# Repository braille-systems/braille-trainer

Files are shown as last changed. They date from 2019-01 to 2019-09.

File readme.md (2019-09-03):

 # Braille Trainer (old repository)
 **New Braille Trainer repositories:** <br>
**[braille3](https://github.com/zuevval/braille3/)** <br>
**[braille3parts](https://github.com/zuevval/braille3parts/)** <hr>

Braille Trainer: a  device and a set of programs in Python made for visually impared. The main purpose is learning Braille alphabet.<br>
**ENG:**<br>
**General information:** [wiki](https://github.com/zuevval/braille/wiki) <br>
**Articles (drafts), information about previous studies:** [папка doc](https://github.com/zuevval/braille/tree/master/doc) <br>
**Progress of the project during FabLab Polytech winter school-2019:** [Projects/1/](https://github.com/zuevval/braille/projects/1) <br>
**Miscellaneous data from a former leader of BrailleTrainer project Gleb Miroshnik:** [Dropbox](https://www.dropbox.com/sh/m1fgdtpio7jf0r5/AADZN6ftSRqo8V_MonHDIt2Xa?dl=0) <br>
**Contacts:** valera.zuev.zva@gmail.com - Валерий Зуев <br>
**YouTube:** [https://www.youtube.com/channel/UC_SwOSaCvuRJdq-IEFu5GWw](https://www.youtube.com/channel/UC_SwOSaCvuRJdq-IEFu5GWw)
<br>
**An application for a contest "Reactor 2019:"** [reactor.su/project/12096](https://reactor.su/project/12096)<br>
<br>
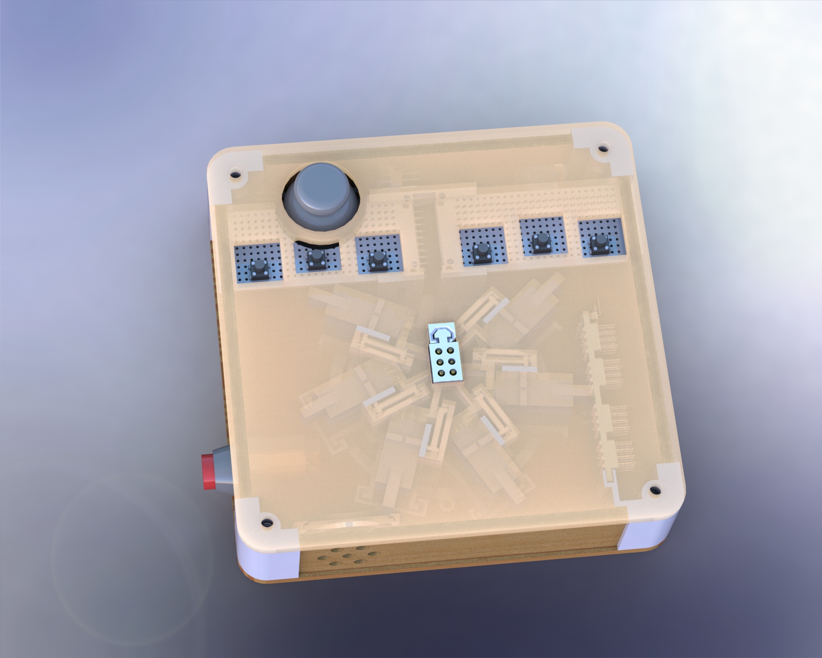
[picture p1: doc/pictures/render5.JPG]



<br>
<br>
**RUS:**<br>
**Основная информация:** [вики](https://github.com/zuevval/braille/wiki) <br>
**Заготовки статей и материалы предшествующих исследований:** [папка doc](https://github.com/zuevval/braille/tree/master/doc) <br>
**Ход проекта в рамках Школы ФабЛаб (зима 2019):** [Projects/1/](https://github.com/zuevval/braille/projects/1) <br>
**Материалы, доставшиеся от Глеба Мирошника:** [Dropbox](https://www.dropbox.com/sh/m1fgdtpio7jf0r5/AADZN6ftSRqo8V_MonHDIt2Xa?dl=0) <br>
**Контакты:** valera.zuev.zva@gmail.com - Валерий Зуев <br>
**YouTube:** [https://www.youtube.com/channel/UC_SwOSaCvuRJdq-IEFu5GWw](https://www.youtube.com/channel/UC_SwOSaCvuRJdq-IEFu5GWw)
<br>
**Заявка на конкурс "Реактор 2019:"** [reactor.su/project/12096](https://reactor.su/project/12096)

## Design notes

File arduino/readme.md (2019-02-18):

**Arduino-код (одна папка - один скетч)** <br>
* calibrate - калибровочный скрипт шеститочечной 
ячейки на серво
* printText общается по Serial с функциями из serial_hex.py и 
joystick.py из папки python. Печатает заданный текст; выводит нажатия джойстика и кнопки 
режима звука. Работает при прямом подключении серво.
* printTextPWM - то же, что printText, но работает при подключении серво 
через 16-канальный импульсный PWM-драйвер

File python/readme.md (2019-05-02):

Для работы синтеза речи в Windows:
1. [download RHVoice (Google Drive)](https://nvda.ru/links/rhvoice-0.7.1-sapi5.php)
Если не устраивает конкретно этот дистрибутив: [RHVoice - все версии, в т. ч. портативная](https://nvda.ru/sintezator-rhvoice#komplekt-rhvoice-v071-sapi5-razdelnye-komponenty)
1. Запустить инсталлер RHVoice (`General/RHVoice-v0.7.1-setup.exe`)
1. После успешной установки запустить инсталлер голоса, сейчас это Ирина (`Voice/RHVoice-voice-Russian-Irina-v4.0-setup.exe`)
1. `pip3 install pyttsx3` - набрать в терминале

После этих действий должны проигрываться названия приложений в меню и прочее (заметки, ...)

Для работы распознования аудио понадобится:
1. ``pip install pyaudio``
1. ``pip install speechrecognition``
1. ``pip install pocketsphinx``

Для установки pocketsphinx может потребоваться установленный swig:
инструкция: http://www.swig.org/download.html
(если установка pocketsphinx проходит нормально через pip, Swig не нужен)

Для работы с Serial используется библиотека pySerial<br>
https://github.com/pyserial/pyserial
https://pythonhosted.org/pyserial/
Для установки `pip install pyserial`

Для работы listen необходимо добавить в папку python'a:
~\Lib\site-packages\pocketsphinx\model
файлы: (содержимое папки "for_ps")
calc.jsgf
my_dicy_out.dic
всю папку zero_ru.cd_cont_4000

Эталонные версии пакетов, с которыми проверена работа:
1. Python 3.7.2
1. PyAudion 0.2.11
1. PyQt5 5.12
1. PyQt5-sip 4.19.14
1. pyserial 3.4
1. SpeechRecognition 3.8.1
1. pocketsphinx 0.1.15

**alphabet.py** - приложение - азбука<br>
**audio.py** отвечает за проигрывание буквы в .wav из папки 
"audio" и вывод остальных фраз; только для Windows<br>
**clock.py** - приложение - часы<br>
**edu.py, edu_app.py** - обучающее приложение<br>
**joystick.py** - обработка нажатий джойстика, 
пришедших по Serial<br>
**letter.py** - вывод буквы на экран в PyQT5<br>
**listen.py** - распознавание произнесённой буквы 
(вариант с сервисом google, если не получается, вызывает pocketsphinx распознование)<br>
**main.py** - **запуск всего (меню 
приложений)**<br>
**notes.py** - приложение - заметки (в 
разработке)<br>
**serial_get_name.py** - автоопределение 
COM-порта, к которому подключён тренажёр<br>
**serial_hex.py** выводит строку (алфавит) в Serial. Соответствует скетчу print_letters в 
папке arduino. Также проигрывает буквы вслух (только на Windows) <br>
**ui_letter.py** - наполнение (дизайн) для 
вывода буквы на экран средствами PyQT5. Логика 
в letter.py<br>

**alphabet.py** - приложение - азбука<br> **audio.py** отвечает за 
проигрывание буквы в .wav из папки "audio" и вывод остальных фраз; 
только для Windows<br> **clock.py** - приложение - часы<br>** **edu.py, 
edu_app.py** - обучающее приложение<br> **joystick.py** - обработка 
нажатий джойстика, пришедших по Serial<br> **letter.py** - вывод буквы 
на экран в PyQT5<br> **listen.py** - распознавание произнесённой буквы 
(вариант с сервисом google)<br> **main.py** - **запуск всего (меню 
приложений)**<br> **notes.py** - приложение - заметки (в разработке)<br> 
**serial_get_name.py** - автоопределение COM-порта, к которому подключён 
тренажёр<br> **serial_hex.py** выводит строку (алфавит) в Serial. 
Соответствует скетчу print_letters в папке arduino. Также проигрывает 
буквы вслух (только на Windows) <br> **ui_letter.py** - наполнение 
(дизайн) для вывода буквы на экран средствами PyQT5. Логика в 
letter.py<br>

Ссылка на описание аудифайлов
https://docs.google.com/spreadsheets/d/1J9BtCmSqfUPkXovssfOHMlftX5HE0grbqLEqsHJY1Zc/edit#gid=0

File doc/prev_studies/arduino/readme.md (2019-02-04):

# Code developed during a period from 2016 to 2018
* drum_2016 - код для кругового дисплея Валеры, написанный Мишей Ракицким
* Остальное - различные версии, написанные Глебом, Савой и другими.

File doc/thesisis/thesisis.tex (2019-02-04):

%XeLaTeX+makeIndex+BibTeX OR LuaLaTeX+...
\documentclass[a4paper,12pt]{article} %14pt - extarticle
\usepackage[utf8]{inputenc} %русский язык, не менять
\usepackage[T2A, T1]{fontenc} %русский язык, не менять
\usepackage[english, russian]{babel} %русский язык, не менять
\usepackage{fontspec} %различные шрифты
\setmainfont{Times New Roman}

%\defaultfontfeatures{Ligatures={TeX},Renderer=Basic}
\usepackage[hyphens]{url} %ссылки \url с переносами
\usepackage{hyperref} %гиперссылки href
\hypersetup{pdfstartview=FitH,  linkcolor=blue, urlcolor=blue, colorlinks=true} %гиперссылки
\usepackage{subfiles}%включение тех-текста
\usepackage{graphicx} %изображения
\usepackage{float}%картинки где угодно
\usepackage{textcomp}

%\usepackage[dvips]{color} %попытка добавить цвета типа OliveGreen. Пропадают все картинки

\usepackage{dsfont}%мат. символы
%\usepackage[style=gost-footnote]{biblatex} %ГОСТ https://www.ctan.org/pkg/biblatex-gost С ним только хуже! Не использовать его!
\newcommand{\ovr}[1]{\overrightarrow{#1}}
\usepackage{listings} %code formatting
\lstset{language=sql,keywordstyle=\color{blue},tabsize=2,breaklines=true,
morekeywords={if, CONCAT, is}}
%хорошая статья об этом пакете: http://mydebianblog.blogspot.com/2012/12/latex.html

\addto\captionsrussian{\def\refname{Использованные источники}}

\begin{document}
\title{Описание проекта <<Тренажёр Брайля>>}
\author{Валерий Зуев}
\maketitle
\section{Краткое описание}
Предлагается собрать и запрограммировать \textbf{тренажёр Брайля} -- прибор для обучения слепых людей \textbf{шрифту Брайля}. Идея шрифта Брайля -- представление буквы в виде группы выпуклых точек, оттиснутых на бумаге или иной поверхности (иногда такие есть на упаковках с лекарствами). Слепые могут читать на ощупь, но должны выучить обозначение каждой буквы.\\
Основной элемент прибора -- электромеханическая \textbf{ячейка Брайля}, которая посредством сервоприводов воспроизводит буквы шеститочечного шрифта Брайля. Планируется, ориентируясь на разработанный заблаговременно прототип ячейки, создать несколько обучающих программ для ПК или одноплатного компьютера Nano Pi. Непосредственно управлять сервоприводами будет контроллер Arduino Uno; планируется написать программу для него. Помимо того, планируется усовершенствовать и доработать ячейку Брайля.

\section{Актуальность}
Число инвалидов по зрению в России по состоянию на 2011 год оценивалось в 103 тысячи человек, и предполагается дальнейшее увеличение их количества\cite{stat}. При этом число людей, владеющих шрифтом Брайля, снижается \cite{brailleLower}. Причина как в относительной дороговизне специальных книг, так и в сложности обучения, в неразвитости системы обучения. При этом знание шрифта Брайля позволяет слепому читать, учиться и даже работать.\\
В настоящее время выпускаются дисплеи Брайля -- приставки к компьютеру с компактными пьезоэлектрическими ячейками. Эти устройства позволяют читать до 80 символов Брайля одновременно и вводить текст с помощью особой клавиатуры из восьми клавиш (по одной на каждую точку в букве азбуки Брайля). Основной их недостаток -- цена (в среднем 150 тысяч русских рублей по состоянию на январь 2019 года).

\section{Предшествующие работы}
Были предприняты многочисленные попытки создания более доступного дисплея Брайля.  В их числе нитиноловые \cite{sma}, на основе электрической стимуляции кожи \cite{kaji1} \cite{kaji2}, на основе электромоторов \cite{bristol}, круговые \cite{rotDisp}. В 2016 году автор статьи пытался разработать собственную конструкцию кругового дисплея Брайля (рис. \ref{myRoundDisp}), но из-за сложности создания миниатюрной механики проект был свёрнут.\\

\begin{figure}[h!]
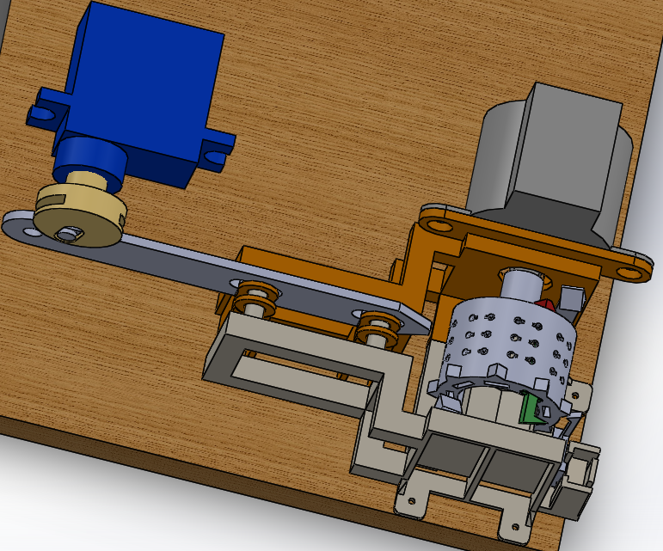
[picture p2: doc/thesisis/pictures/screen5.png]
\center{}
\caption{Компьютерная модель нереализованного кругового дисплея Брайля}
\label{myRoundDisp}
\end{figure}

В 2016-2017 годах команда под руководством магистра кафедры <<Теоретическая Механика>> Глеба Андреевича Мирошника создала несколько прототипов тренажёра Брайля - дисплея с одной ячейкой, ориентированного на обучение слепых, а не на длительное чтение \cite{gleb}. После ряда попыток создать ячейку Брайля на основе сервоприводов было решено отказаться от них в пользу обычной, более надёжной пьезоэлектрической ячейки. Такой тренажёр компактный, но трудновоспроизводимый: ячейки дисплея Брайля, по имеющимся данным, не продаются отдельно от дисплеев.

\section{Цели работы}
Цель - создать надёжный и простой в изготовлении тренажёр Брайля и комплекс программ для него. Предлагается развить идею, реализованной командой Г. А. Мирошника. Ячейка Брайля будет создана с применением только доступных компонентов (сервоприводов, контроллеров Arduino и/или Raspberry Pi, деталей, пригодных к изготовлению на большинстве 3D-принтеров). За счёт открытого распространения материалов проекта предполагается возможным легко воспроизводить дисплей и сделать обучение шрифту Брайля доступным для людей по всему миру.

\section{Описание конструкции}
Создан прототип ячейки (рис. \ref{photo1}). Точки символа Брайля - головки подвижных штырьков. Штырьки приклеены к рычагам и двигаются вверх-вниз, отчего точки появляются над поверхностью или убираются внутрь. Движение обеспечивают сервоприводы с насаженными на вал шестернями. Каждый рычаг на противоположном от штырька конце имеет зубчатую рейку, которой передаётся движение шестерни.

\begin{figure}[h!]
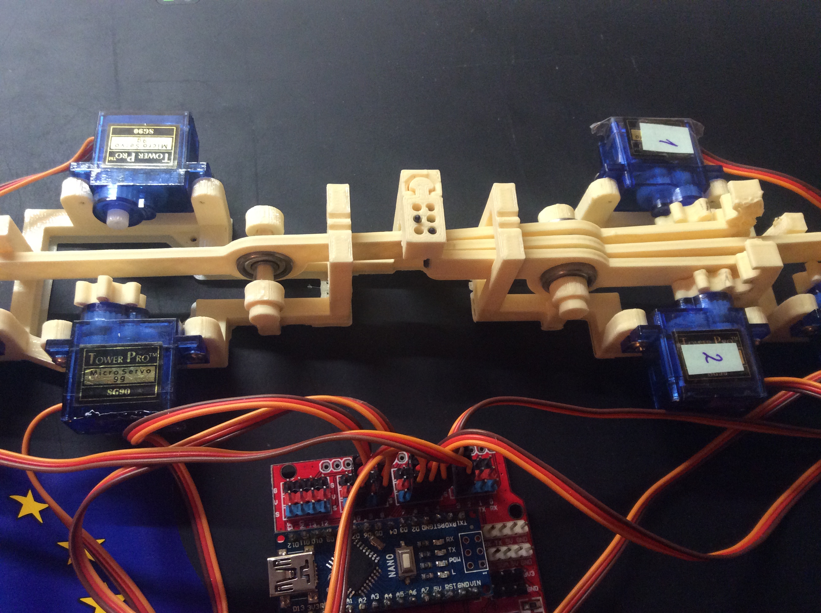
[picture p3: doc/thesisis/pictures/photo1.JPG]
\center{}
\caption{Прототип ячейки Брайля}
\label{photo1}
\end{figure}

\section{Текущие задачи и планируемое решение задач}
\subsection{Базовые задачи}
\begin{itemize}
\item{}Написать программу для Arduino, которая выводит текст, отправленный через Serial.
\item{}Снабдить дисплей органами управления (кнопки или джойстик). По нажатию кнопки передавать сигнал по Serial.
\item{}Составить два обучающих приложения на Python, общающихся с Arduino через Serial. Одно для запоминания азбуки: воспроизводит на экране буквы и сопровождает звуком; второе - тест на знание азбуки: дисплей выводит букву, пользователь должен произнести её вслух. Компьютер определяет с помощью распознавания голоса, верно ли ответил пользователь.
\item{}Спроектировать и создать корпус устройства
\item{}Разместить материалы проекта в свободном доступе (к примеру, на платформе Github), чтобы предоставить возможность создания подобного прибора всем желающим.
\end{itemize}
\subsection{Приблизительный список дополнительных задач}
\begin{itemize}
\item{}Адаптировать программы на Python к контроллеру Raspberry Pi/Nano Pi. Создать отдельный опциональный модуль хост-контроллера с динамиком и микрофоном в собственном корпусе.
\item{}Составить меню тренажёра Брайля (список приложений) с возможностью навигации джойстиком. Названия пунктов меню выводятся с помощью ячейки Брайля или произносятся вслух динамиками компьютера.
\item{}Написать иные программы (обучающие или, возможно, для чтения текста). Пример - часы (показать время с помощью ячейки Брайля).
\item{}Повысить компактность ячейки Брайля: взять подшипники меньшего размера, перекомпоновать сервоприводы (разместить два из них на другой стороне рычагов).
\item{}Попробовать управлять серво с помощью ШИМ контроллера PCA9685
\item{}Создать ячейку с восемью точками (расширенный шрифт Брайля).
\item{}Снабдить тренажёр особой клавиатурой из восьми клавиш. Снабдить встроенным динамиком и, возможно, лампочками для зрячего иструктора (индикатор питания и подключения хост-контроллера).
\item{}Предусмотреть в конструкции механизм для автокалибровки ячейки.
\item{}Уделить внимание не техническим аспектам (презентовать проект, возможно, создать видеоклип/сайт проекта).
\end{itemize}

\begin{thebibliography}{99}
\bibitem{gleb}{Тренажёр Брайля. Глеб Андреевич Мирошник. [Электронный ресурс] \url{http://www.brailletrainer.ru}}
\bibitem{sma}{Microtuators of SMA for Braille display system \url{https://www.researchgate.net/publication/232633029_Microtuators_of_SMA_for_Braille_display_system}}
\bibitem{kaji1}{Electro-Tactile Display with Force Feedback. Hiroyuki Kajimoto, Naoki Kawakami, Taro Maeda and Susumu Tachi: Graduate School of Information Science and Technology, The University of Tokyo. [Электронный ресурс]. \url{http://citeseerx.ist.psu.edu/viewdoc/download?doi=10.1.1.493.2786&rep=rep1&type=pdf}}
\bibitem{kaji2}{Electro-Tactile Display with Tactile Primary Color Approach.
Hiroyuki Kajimoto, Naoki Kawakami, Susumu Tachi. Graduate School of
Information Science and Technology, The University of Tokyo.  [Электронный ресурс]. \url{http://files.tachilab.org/publications/intconf2000/kajimoto200410IROS.pdf}}
\bibitem{bristol}{Bristol Braille technology [Электронный ресурс] \url{http://bristolbraille.co.uk}}
\bibitem{rotDisp}{Refreshable braille reader. John W. Roberts, Oliver T. Slattery, David W. Kardos. [Электронный ресурс] \url{https://patents.google.com/patent/US6776619}}
\bibitem{stat}{Оценка динамики и прогноз первичной инвалидности в Амурской области вследствие офтальмопатологии. Выдров А. С. [Электронный ресурс] \url{https://cyberleninka.ru/article/v/otsenka-dinamiki-i-prognoz-pervichnoy-invalidnosti-v-amurskoy-oblasti-vsledstvie-oftalmopatologii}}
\bibitem{brailleLower}{Актуальность рельефно-точечного шрифта по системе брайля в современном мире. [Электронный ресурс] \url{https://beltiz.by/talking/1068-2013-12-19-11-49-03}}
\bibitem{blindLib1}{М. П. Коновалова,  О. Ю. Жарова. Технические средства реабилитации для людей с ограниченными возможностями (на примере опыта работы Калужской областной специальной библиотеки для слепых им. Н. Островского) (окончание). [Электронный ресурс] \url{https://cyberleninka.ru/article/v/tehnicheskie-sredstva-reabilitatsii-dlya-lyudey-s-ogranichennymi-vozmozhnostyami-na-primere-opyta-raboty-kaluzhskoy-oblastnoy-1}}
\end{thebibliography}
\end{document}

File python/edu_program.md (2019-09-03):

По книге В. К. Рогушина, М. Б. Потешиной, М. С. Сорокиной "Обучение взрослых слепых письму и чтению по системе Брайля", ООО "ИПТК "Логос" ВОС", М., 2005
*Идея. Добавить в тренажёре горячее сочетание клавиш, которое сообщает разработчикам о ошибке в этом месте (с необязательным комментарием)*
#Основны

##1. Знакомство с системой Брайля

##2. Знакомство с системой Брайля. Продолжение

##3. Буквы А, М, У

##4. Буквы К., Л.
*После знакомства с "к" необходимо проследить структурную связь между м, к, у*
*При знакомстве с Л обращать внимание на форму (столбик из трёх точек)*
1. Прочитайте слова: мама ум ума ау уму ау мама ума
1. Перед вами буква К. Где находятся точки, её составляющие? Какие они имеют номера?
1. Ответ: точки 1 и 3, слева наверху и слева внизу.
1. Наберите букву К.
1. Какую точку надо добавить к букве К, чтобы получить М? (точку 4)
1. Наберите букву у.
1. Что надо сделать с буквой у, чтобы получить к?
1. Ответ: удалить шестую точку.
1. мак, мука, мама, кум, кума, как 
1. Добавим к букве К точку номер 2. Сколько точек в полученной комбинации?
1. Тремя точками - все в левом столбце - обозначается буква Л. Запомните, Л - точки 1, 2, 3, расположены в форме столбика.
1. Лук, лама, кукла, кулак

##5. Буква Р. Знак препинания - "Литературная точка"
*Р - первый знак из четырёх точек. Основная трудность записи - постановка средних точек 2 и 5, особенно 5*
*Наличие точек 2 и 5 в литературной точке также вносит определённые трудности*

1. Наберите букву Л. Какие точки её составляют?
1. Ответ: точки 1, 2, 3
1. Введите такую же комбинацию, но с точкой 5.
1. Точками 1, 2, 3, 5 обозначается буква р
1. Прочитайте слова с буквой Р: (не указаны)
1. В плоскопечатном письме конец предложения обозначается крупной точкой внизу строки. Сейчас на ячейку выведена точка, как её принято обозначать в системе Брайля. Какие точки Брайля составляют литературную точку?
1. Ответ - точки 2, 5, 6. Можно заметить, что литературная точка образована точками нижней части шеститочия, по аналогии с плоскопечатной точкой.
1. Рамка мала. У Макара лак. Лука у Макара.

##6. Буква и, запятая, тире, дефис, знак переноса.

*К этому занятию рекомендовано разделить на группы: сильные/слабые. На тренажёре , наверное, просто стоит корректировать задания, исходя из числа ошибок в тестах*

1. Перед вами буква и. Подумайте, как можно описать её рельефно-точечный состав, то есть какие точки её составляют?
1. Ответ: буква и - номер 2 (левая средняя) и 4 (правая верхняя)
1. Наберите бкуву И.
1. (Чтение одно-, двух-, трёхсложных слов)
1. Запятая обозначается точкой 2 - левой средней точкой
1. Назовите буквы, написанные через запятую: а, м, у, к, л, р, и
1. (Чтение слов с запятой и точкой)
1. Замечание: запятая пишется слитно с последней буквой предыдущего слова, отдельно от первой буквы следующего
1. Тире: графически, в обычном письме тире - горизонтальный штрих по центру строки. Так же и по Брайлю: тире - точки 3, 6
1. (Предложения с тире). Замечание: тире примыкает к последней букве предыдущего слова и отделяется пробелом от следующего
1. Замечание: знак из точек 3 и 6 также служит знаком переноса и дефисом (Москва-река, Иван-город)
1. Кирилл, Карл, Макар - лирики.
1. У Лили кукла Алла.
1. У Кирилла маки, а у Макара раки.
1. Римма и Клара - карлики.
1. Мурка мала.

##7. Буква Ш, цифровой знак. Цифры 1, 2
1. Из каких точек состоит изученная на прошлом уроке буква И?
1. Ответ: из точек 2, 4
1. Наберите букву Р.
1. Как из буквы К получить букву Л?
1. Наберите букву М.
1. Наберите букву У.
1. Какие знаки препинания вы знаете? (Точку, запятую, тире)
1. Наберите предложения: "Ура - крик. У Кирилла мама, Ира и Карл."
1. Наберите знак из точек 1, 5, 6. Это буква Ш.
1. Напишите: шалаш, шашка, кукушка
1. Цифры по системе Брайля - двузнаковый обхект (сочетание двух рельефно-точечных комбинаций)
1. Первый компонент - цифровой знак, второй - буква, соответствующая рассматриваемой цифре
1. Перед вами цифровой знак. Из каких точек он состоит?
1. Ответ: из точек 3, 4, 5, 6
1. Наберите этот знак
1. Наберите знак и после него букву А. Это цифра 1
1. Цифра 2 обозначается цифровым знаком и вторым знаком, который перед вами. Каки точки входят во второй знак цифры 2?
1. Ответ: точки 1 и 2
1. Прочитайте: 1212
1. (Чтение предложений с цифрами)
1. Замечание: в предложениях перед цифрой и после неё пропускается одна клеточка

##8. Буквы о, е, цифры 5, 9
*е получается из о удалением третьей точки. Часто учащиеся путают Е и И, особенно на письме.*
*Это преодолевается тренировкой и специальной методикой различения*

1. (Под диктовку - 1 или 2 предложения с буквой Ш, цифрами 1, 2)
1. У Мишки 2 шашки и 1 рамка.
1. К шалашу или 2 шакала.
1. У Маши 1 кушак.
1. Для сильных учащихся - ещё 1-2 предложения
1. Перед вами буква О. Где располагаются точки, её составляющие? Какие у них номера?
1. Ответ: слева вверху, слева внизу, справа посередине. Номера, составлающие букву О - 1, 3, 5.
1. Наберите букву О.
1. Чтение (сообразно с успехами учащегося)
1. Наберите символы, входящие в букву О, без точки 3. Какие точки составляют новый знак?
1. Ответ: знак составлен точками 1 и 5.
1. Замечание: буква Е по Брайлю напоминает наклонную короткую чёрточку из точек 1 и 5
1. Придумайте и запишите 4 слова с буквой Е
1. Наберите букву И. Что можно сказать о различии и сходстве букв Е и И? (Они - зеркальное отображение друг друга. Не путайте!)
1. Мера
1. ели
1. море
1. крем
1. реле
1. реки
1. мели
1. мерка, кролик, уроки
1. Наберите цифровой знак, а после него букву Е.
1. Это сочетание обозначает цифру 5. Наберите ещё раз.
1. Аналогично изучается цифра 9.
1. Оставшееся время занятие - предложения с буквами И и Е. Списывание одного предложения на выбор.
 *Возможно, списывание имитировать произношением части предложения во время набора после каждой ошибки и после каждого слова?*

##9. Буква Н
*Сложна для чтения и письма, поэтому на её изучение отводится достаточно много времени*

1. Наберите букву М.
1. Наберите букву М, добавив к ней 5 точку. Сколько точек получилось и каковы их номера?
1. Ответ: знак содержит 4 точки с номерами 1, 3, 4, 5. Эта комбинация служит для обозначения буквы Эн.
1. Какое местоположение у каждой точки буквы Эн?
1. Ответ: первая точка находится слева наверху, третья - слева внизу, четвёртая - справа наверху, пятая - справа посередине.
1. Наберите букву Н ещё раз.
1. Прочитайте слова. Выпишите из них те, которые являются именами.
*По пособию, учитель должен контролировать, чтобы читали двумя руками. Здесь этого сделать нельзя*
1. Прочитайте предложения. Старайтесь запомнить их и повторять вслух после прочтения. Спишите одно на выбор.
1. Разделите все изученные буквы на три группы. В первую поместите буквы, содержащие первую точку, но не содержащие четвёртую. Во вторую - с четвёртой, но без первой. В третьей - и первую, и четвёртую.
1. Как из Л получить букву Р?
1. Ответ: добавить к Л точку 5. А как из Ш получить букву Е?
1. Ответ: убрать точку 6
1. Как из буквы М получить У?
1. Ответ: убрать четвёртую точку и добавить точку 6.

##10. Буква С. Различение букв С и Ш.
*Сначала повторяем Ш и Н*

1. Диктант: шина, шнур, мишура, налим, машина, ниша, кулон, ноша
1. Чтение: Маша шла и шар нашла. Наша Нина у окна.
1. *Изучение модели буквы С из плотного картона/линолеума с наклеенными пуговицами/заклёпками в нужных местах. Для ориентации в нижней части модели вырезается уголок.*
1. Перед вами буква С. Укажите местоположение точек в букве при её чтении (Слева посередине, слева внизу, справа наверху)
1. Назовите номера точек в букве С.
1. Ответ: точки 2, 3, 4
1. Замечание: по форме брайлевское изображение буквы С напоминает дугу, схожую с плоскопечатной буквой С.
1. Наберите букву С
1. Ещё раз назовите точки, входящие в букву С
1. Придумайте и запишите 5 слов с буквой С: два односложных, два двусложных, два трёхсложных
1. (Чтение строк в букваре)
1. (Напишите ряд буквы С и ряд буквы Ш). В чём сходство и различие между буквами С и Ш?
1. Правильный ответ: как С, так и Ш имеют форму дуги, но дуги по-разному расположены. Буква Ш - зеркальное изображение буквы С.
1. Диктант: Саша, шасси, шоссе, шанс, сушка, шест, шелест.
1. Воспроизведение ранее изученных букв

##11. Буква Т, цифра 3. Вопросительный знак.
*Трудность изучения буквы Т в том, что это многоточечный знак*
*Логично изучать Т позже, но Т часто встречается в русском и нужна для чтения*
*Средние точки находить труднее, а их в Т две*
*Перед изучением "?" надо напомнить, что знаки препинания, в отличие от букв, не содержат верхних точек шеститочия. Не следует путать знак вопроса с Е.*

##12. Буква Ы, дифференциация букв Н и Ы

##13. Буква Д, цифра 4

##14. Буква Б, Г, цифра 7

##15. Буквы П, Х, цифра 8

##16. Буква В. Различение букв В и Р

##17. Буква Ж, цифра 0. Упражнения на различение букв Д, Ж, Х

##18. Буква З. Дифференциация букв З, Ы, Н

##19. Буква Й. Восклицательный знак

##20. Мягкий знак, кавычки

##21. Буква Ё, двоеточие

##22. Буква Ч

##23. Буква Я, упражнения на различение букв Н, Ы, З, Я

##24. Буква Ю. Различение букв Ю и Т

##25. Буква Ф, цифра 6, двоеточие

##26. Буквы Щ, Ц

##27. Буквы Э, Ъ. Знаки препинания: точка с запятой, литературные скобки

##28. Знаки препинания, ударение. Упражнения на их применение

#Послебукварное чтение

##29. Систематизация записи по системе Брайля арабских цифр. Закрепление навыков их чтения и письма.

##30. Знаки арифметических действий. Круглые скобки

##31. Признаки прописных и строчных букв алфавита. Упражнения на применение прописных букв русского алфавита.

##32. Знаки выделения шрифтов

*Следующее: римские цифры, дроби... в наш курс, пожалуй, не войдут*

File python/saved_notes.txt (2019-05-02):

сегодня была солнечная погода\
катался на велосипеде\
сделал лабораторную работу\
в заметках асинхронный синтез речи не реализован\
нужно будет в заметках дополнить ввод пробела\
а\
аб1\
а1\

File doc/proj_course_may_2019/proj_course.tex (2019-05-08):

%XeLaTeX+makeIndex+BibTeX OR LuaLaTeX+...
\documentclass[a4paper,12pt]{article} %14pt - extarticle
\usepackage[utf8]{inputenc} %русский язык, не менять
\usepackage[T2A, T1]{fontenc} %русский язык, не менять
\usepackage[english, russian]{babel} %русский язык, не менять
\usepackage{fontspec} %различные шрифты
\setmainfont{Times New Roman}

%\defaultfontfeatures{Ligatures={TeX},Renderer=Basic}
\usepackage[hyphens]{url} %ссылки \url с переносами
\usepackage{hyperref} %гиперссылки href
\hypersetup{pdfstartview=FitH,  linkcolor=blue, urlcolor=blue, colorlinks=true} %гиперссылки
\usepackage{subfiles}%включение тех-текста
\usepackage{graphicx} %изображения
\usepackage{float}%картинки где угодно
\usepackage{textcomp}

\usepackage{dsfont}%мат. символы
%\usepackage[style=gost-footnote]{biblatex} %ГОСТ https://www.ctan.org/pkg/biblatex-gost С ним только хуже! Не использовать его!

\addto\captionsrussian{\def\refname{Использованные источники}}

\begin{document}
\title{Устройство для обучения незрячих чтению рельефным шрифтом <<Тренажёр Брайля>>}
\maketitle
Добрый день. Мы - команда из ИПММ - расскажем о техническом и социальном проекте <<Тренажёр Брайля>>.\\ %титульный слайд
Общественное положение людей с нарушениями зрения даже сейчас нельзя назвать завидным. За примерами далеко ходить не надо. Недалеко от Политеха лет пятнадцать назад ещё работал небольшой завод <<Контакт>>, где были созданы условия для работы слепых. Теперь завод закрыт, здание снесено, на его месте будут возводить жилой дом.\\ %человек с тростью
Вдобавок ко всем несчастьям слепой не может читать и писать. Впрочем, уже давно француз Луи Брайль изобрёл рельефно-точечный шрифт - символы, накалываемые на плотной бумаге (иногда встречаются на упаковках лекарств).\\ %шрифт Брайля
В последние десятилетия, к сожалению, число грамотных по Брайлю падает, хотя слепых в России и мире всё больше. Главная причина - обучение недоступно большинству незрячих. Специализированные школы и центры если и есть, то только в городах, да и в городе слепой по понятным причинам не может ездить далеко от дома. Аппаратура для реабилитации стоит дорого, например, дисплей Брайля - не менее ста тысяч рублей.\\ %слайд с дисплеем Брайля
В мастерской ФабЛаб Политех с 2016 года под руководством Глеба Андреевича Мирошника разрабатывается тренажёр Брайля - аппарат с одной ячейкой, имитирующей любой символ шеститочечного алфавита Брайля. Было создано несколько демонстрационных образцов с пьезоэлектрическими ячейками из фабричного дисплея Брайля.\\ %фото Глеба Андреевича с сайта и видео работы устройства
Зимой мы сделали тренажёр с самодельной механической ячейкой и контроллером Arduino. К нему написали несколько программ на Python и тренажёр мог, общаясь с компьютером через USB, вывести азбуку, часы и несколько уроков с голосовым сопровождением. \\ %фото, м. б. видео работы
В рамках курса мы собрали команду \textit{(Лёша, увы, в Соединённых Штатах)}. Изначально планировали создать два прибора и более развитые программы. Один прибор - улучшенная модель предыдущего, другой - полностью автономный интерактивный прибор под управлением одноплатного компьютера с операционной системой Linux. Особенность тренажёра - низкая стоимость изготовления, 2-4 тысячи рублей за штуку, поэтому спонсоров не искали.\\ %слайд с командой
Начали с создания ячейки. Шесть севоприводов - шесть точек Брайля. Шестерёнки двигают рейки вверх-вниз. \\ %слайд с ячейкой Брайля - с моделью
Затем подключили джойстик, спаяли шестикнопочную клавиатуру, динамик. На лазерном станке вырезали корпус. Сделали накладки на USB-кабель с надписями по Брайлю - "Верх".\\ %Видео и/или фото в проекциях + кабель
Программисты тем временем сделали приложение - заметки, калькулятор, блиц-опрос. Занялись голосовым распознаванием, которое нужно для ответов в проверочных тестах. \\ %просто код и ветки, м. б. ускоренное видео
К апрелю один аппарат был сделан, и мы поехали с ним в Общество Слепых. \\ %фото устройства
В региональной организации Общества Слепых в целом похвалили работу. Но экспертам не понравилась попытка озвучить уроки живым голосом. Сказали, нужен либо профессиональный диктор, либо синтезатор. \\ %видео или фото с Ниной Константиновной (б/звука)
Тогда мы подключили синтезатор RHVoice. Помимо прочего, теперь можно менять скорость воспроизведения.\\ %видео смены скорости
Начали экспериментировать с одноплатным компьютером, но тут не всё пошло по плану. Долго пытались, но не смогли подключить драйвер сервоприводов.\\ %видео
Тогда мы сделали устройство как и раньше, на Arduino, но добавили клавишу пробел и клавишу помощи. Нажав на клавишу помощи, можно услышать подсказки, в каком приложении Вы находитесь и что можно сделать.
Тренажёр имеет размеры 150*150*35 мм, питается от адаптера на 5V 2А. Последний вариант имеет защиту от неправильного подключения: если подключить только провод USB, моторы работать не будут. \\ %слайд со вторым тренажёром или взрыв-схема
В итоге у нас есть достаточно продвинутая механика и развитые программы (более двух тысяч строк кода на GitHub). Но если тренажёр был создан в нескольких экземплярах, всякий раз лучше, то программы строились постепенно с самого начала, и остались некоторые недочёты. Летом я хочу сделать новую модель механики. Осенью планирую вновь собрать команду и переписать программы на Java, в том числе, чтобы можно было подключаться не только к компьютеру, но и к смартфону с Android.\\ % слайды с взрыв-схемой, электрической схемой
Спасибо за внимание. Проект полносьтью открытый, подробную информацию можно найти по ссылке на GitHub. \\ %слайд с благодарностями и ссылкой на GitHub
%Запасные слайды: Умка-01 и Taptilo; Nano Pi; алафвит Брайля; устройство ячейки, старой ячейки, пьезоэлектрической ячейки. Списки библиотек Python, RHVoice. GitHub - ветки, проект. Евгений и нейросеть
\end{document}

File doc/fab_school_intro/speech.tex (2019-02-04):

%XeLaTeX+makeIndex+BibTeX OR LuaLaTeX+...
\documentclass[a4paper,12pt]{article} %14pt - extarticle
\usepackage[utf8]{inputenc} %русский язык, не менять
\usepackage[T2A, T1]{fontenc} %русский язык, не менять
\usepackage[english, russian]{babel} %русский язык, не менять
\usepackage{fontspec} %различные шрифты
\setmainfont{Times New Roman}

%\defaultfontfeatures{Ligatures={TeX},Renderer=Basic}
\usepackage[hyphens]{url} %ссылки \url с переносами
\usepackage{hyperref} %гиперссылки href
\hypersetup{pdfstartview=FitH,  linkcolor=blue, urlcolor=blue, colorlinks=true} %гиперссылки
\usepackage{subfiles}%включение тех-текста
\usepackage{graphicx} %изображения
\usepackage{float}%картинки где угодно
\usepackage{textcomp}

%\usepackage[dvips]{color} %попытка добавить цвета типа OliveGreen. Пропадают все картинки

\usepackage{dsfont}%мат. символы
%\usepackage[style=gost-footnote]{biblatex} %ГОСТ https://www.ctan.org/pkg/biblatex-gost С ним только хуже! Не использовать его!
\newcommand{\ovr}[1]{\overrightarrow{#1}}
\usepackage{listings} %code formatting
\lstset{language=sql,keywordstyle=\color{blue},tabsize=2,breaklines=true,
morekeywords={if, CONCAT, is}}
%хорошая статья об этом пакете: http://mydebianblog.blogspot.com/2012/12/latex.html

\addto\captionsrussian{\def\refname{Использованные источники}}

\begin{document}
\title{Устройство для обучения незрячих чтению рельефным шрифтом <<Тренажёр Брайля>>}
\author{Валерий Зуев}
%\maketitle
Добрый день. Я расскажу вам про тренажёр для обучения чтению по системе Луи Брайля незрячих людей. В качестве вступления послушайте короткую историю о слепых людях.\\
Десять лет назад недалеко от Политеха, стоял небольшой завод под названием Контакт. На этом заводе работали слепые. Они делали игрушки, ещё что-то. Слепых селили в домах неподалёку, и для них была специальная инфраструктура. Но лет десять назад завод был закрыт, а затем и снесён. На его месте собираются возводить жилой дом.\\
Это  я к тому, насколько тяжело инвалидам по зрению жить нормальной жизнью. Но хорошим подспорьем для слепого человека стало бы умение читать и писать специальным рельефным шрифтом Брайля. (слайд). Сейчас появились аудиокниги и прочая электроника, но знание азбуки Брайля до сих пор полезно. Чтение (даже по Брайлю) - это приятно, возможность делать заметки разгружает память, а главное, это очень помогает найти работу, помогает найти хоть какую-то занятость. \\
(слайд) В стенах ФабЛаб'а под руководством Глеба Андреевича Мирошника велись разработки тренажёра Брайля - самоучителя для освоения рельефного шрифта в домашних условиях, без преподавателей и дорогого оборудования. Были построены несколько прототипов; непременный элемент тренажёра - ячейка Брайля (слайд, м. б. с видео), которая выводит любой символ шеститочечной системы. Незрячий ощупывает ячейку и учит либо повторяет символы. \\
Глеб Андреевич в своих прототипах использовал пьезоэлектрические ячейки, которые не встречаются в свободной продаже.  (слайд) Наша команда планирует сделать тренажёр с иной ячейкой, где вместо пьезопластинок точки формируются электромоторами. Получается громоздко, но зато такая ячейка Брайля производится из доступных компонентов. Я думаю, родственники незрячего без труда смогут приобрести подобный тренажёр, а, может, и сделать самостоятельно, если у них есть 3D-принтер. В течение школы мы хотим сделать само устройство и написать несколько программ для него,  главным образом - обучающее приложение с использованием распознавания голоса. Я надеюсь, появление такого несложного тренажёра и программ к нему сделают обучение системе Брайля более лёгким делом.\\
Спасибо ФабЛаб'у за предоставление питательной почвы для проекта. Спасибо моим товарищам, пришедшим работать со мной, особенно Ивану и Евгению из Дальневосточного Федерального университета. Евгений будет не только программистом, но и нашим незрячим экспертом. Команда уже сформирована; если Вам очень хочется присоединиться, лучше поговорить со мной отдельно.\\
Благодарю за внимание.
\end{document}

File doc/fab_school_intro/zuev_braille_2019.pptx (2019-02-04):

## Устройство для обучения незрячих чтению рельефным шрифтом «Тренажёр Брайля»

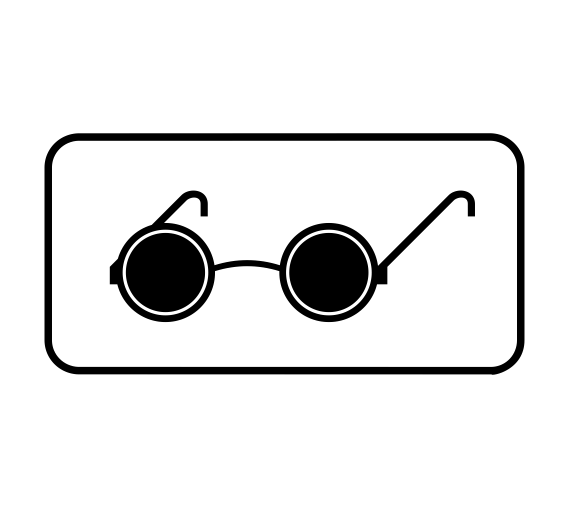
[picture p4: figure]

Валерий Зуев, Алексей Клопов, Евгений Самутичев, Евгений Некрасов, Иван Устюгов, Павел Лапотников
Санкт-Петербург
2019

## Завод «Контакт»

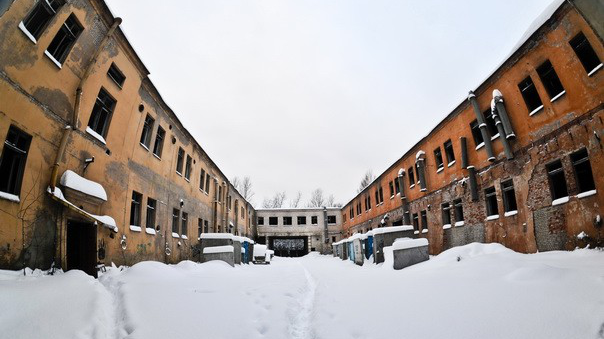
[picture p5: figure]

## Рельефный шрифт Луи Брайля

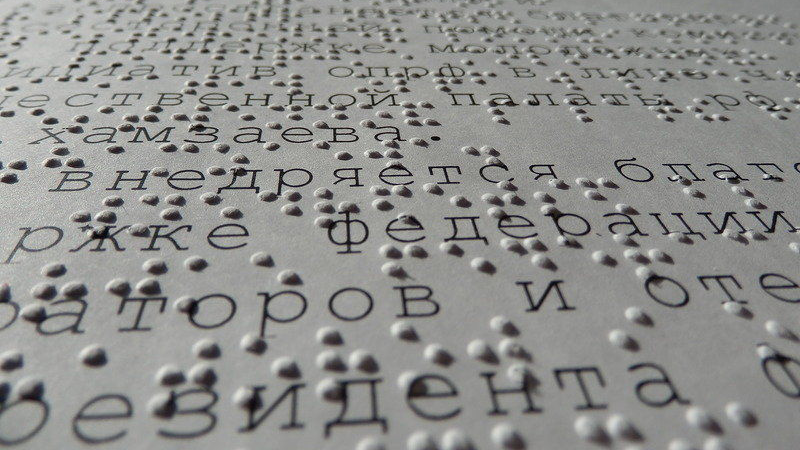
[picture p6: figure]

## Разработки Глеба Андреевича Мирошника

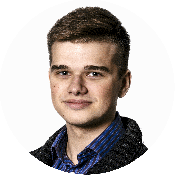
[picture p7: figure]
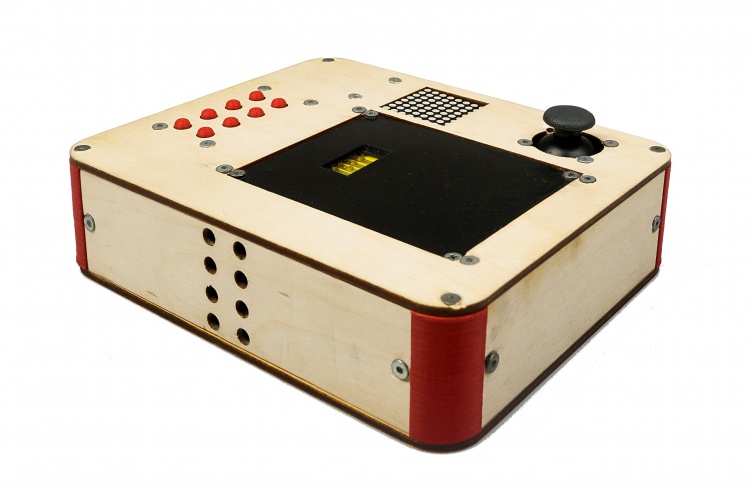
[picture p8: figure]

## Пьезоэлектрические ячейки Брайля

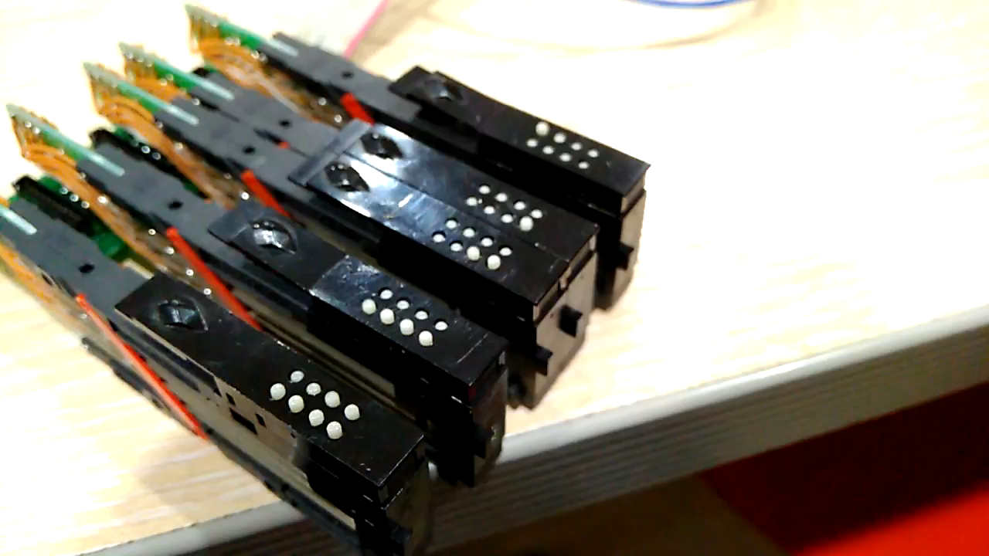
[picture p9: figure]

## Модель нового тренажёра

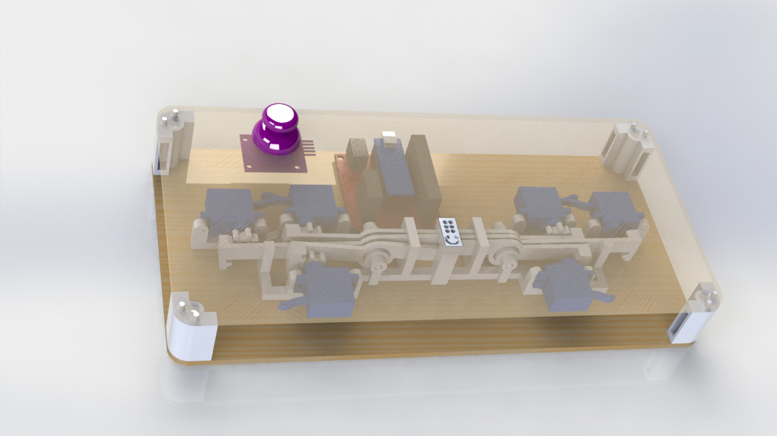
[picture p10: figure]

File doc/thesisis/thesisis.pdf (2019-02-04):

# Описание проекта «Тренажёр Брайля»

### Валерий Зуев

28 января 2019 г.

## 1 Краткое описание

Предлагается собрать и запрограммировать тренажёр Брайля – прибор для обучения слепых людей шрифту Брайля. Идея шрифта Брайля – представление буквы в виде группы выпуклых точек, оттиснутых на бумаге или иной поверхности (иногда такие есть на упаковках с лекарствами). Слепые могут читать на ощупь, но должны выучить обозначение каждой буквы. Основной элемент прибора – электромеханическая ячейка Брайля, которая посредством сервоприводов воспроизводит буквы шеститочечного шрифта Брайля. Планируется, ориентируясь на разработанный заблаговременно прототип ячейки, создать несколько обучающих программ для ПК или одноплатного компьютера Nano Pi. Непосредственно управлять сервоприводами будет контроллер Arduino Uno; планируется написать программу для него. Помимо того, планируется усовершенствовать и доработать ячейку Брайля.

## 2 Актуальность

Число инвалидов по зрению в России по состоянию на 2011 год оценивалось в 103 тысячи человек, и предполагается дальнейшее увеличение их количества[7]. При этом число людей, владеющих шрифтом Брайля, снижается [8]. Причина как в относительной дороговизне специальных книг, так и в сложности обучения, в неразвитости системы обучения. При этом знание шрифта Брайля позволяет слепому читать, учиться и даже работать.
В настоящее время выпускаются дисплеи Брайля – приставки к компьютеру с компактными пьезоэлектрическими ячейками. Эти устройства позволяют читать до 80 символов Брайля одновременно и вводить текст с помощью особой клавиатуры из восьми клавиш (по одной на каждую точку в букве азбуки Брайля). Основной их недостаток – цена (в среднем 150 тысяч русских рублей по состоянию на январь 2019 года).

1

## 3 Предшествующие работы

Были предприняты многочисленные попытки создания более доступного дисплея Брайля. В их числе нитиноловые [2], на основе электрической стимуляции кожи [3] [4], на основе электромоторов [5], круговые [6]. В 2016 году автор статьи пытался разработать собственную конструкцию кругового дисплея Брайля (рис. 1), но из-за сложности создания миниатюрной механики проект был свёрнут.


Рис. 1: Компьютерная модель нереализованного кругового дисплея Брайля

В 2016-2017 годах команда под руководством магистра кафедры «Теоретическая Механика» Глеба Андреевича Мирошника создала несколько прототипов тренажёра Брайля - дисплея с одной ячейкой, ориентированного на обучение слепых, а не на длительное чтение [1]. После ряда попыток создать ячейку Брайля на основе сервоприводов было решено отказаться от них в пользу обычной, более надёжной пьезоэлектрической ячейки. Такой тренажёр компактный, но трудновоспроизводимый: ячейки дисплея Брайля, по имеющимся данным, не продаются отдельно от дисплеев.

2

## 4 Цели работы

Цель - создать надёжный и простой в изготовлении тренажёр Брайля и комплекс программ для него. Предлагается развить идею, реализованной командой Г. А. Мирошника. Ячейка Брайля будет создана с применением только доступных компонентов (сервоприводов, контроллеровArduino и/или Raspberry Pi, деталей, пригодных к изготовлению на большинстве 3D-принтеров). За счёт открытого распространения материалов проекта предполагается возможным легко воспроизводить дисплей и сделать обучение шрифту Брайля доступным для людей по всему миру.

## 5 Описание конструкции

Создан прототип ячейки (рис. 2). Точки символа Брайля - головки подвижных штырьков. Штырьки приклеены к рычагам и двигаются вверх-вниз, отчего точки появляются над поверхностью или убираются внутрь. Движение обеспечивают сервоприводы с насаженными на вал шестернями. Каждый рычаг на противоположном от штырька конце имеет зубчатую рейку, которой передаётся движение шестерни.


Рис. 2: Прототип ячейки Брайля

3

## 6 Текущие задачи и планируемое решение задач

### 6.1 Базовые задачи

- Написать программу для Arduino, которая выводит текст, отправленный через Serial.
- Снабдить дисплей органами управления (кнопки или джойстик). По нажатию кнопки передавать сигнал по Serial.
- Составить два обучающих приложения на Python, общающихся сArduino через Serial. Одно для запоминания азбуки: воспроизводит на экране буквы и сопровождает звуком; второе - тест на знание азбуки: дисплей выводит букву, пользователь должен произнести её вслух. Компьютер определяет с помощью распознавания голоса, верно ли ответил пользователь.
- Спроектировать и создать корпус устройства
- Разместить материалы проекта в свободном доступе (к примеру, на платформе Github), чтобы предоставить возможность создания подобного прибора всем желающим.

### 6.2 Приблизительный список дополнительных задач

- Адаптировать программы на Python к контроллеру Raspberry Pi/Nano Pi. Создать отдельный опциональный модуль хост-контроллера с динамиком и микрофоном в собственном корпусе.
- Составить меню тренажёра Брайля (список приложений) с возможностью навигации джойстиком. Названия пунктов меню выводятся с помощью ячейки Брайля или произносятся вслух динамиками компьютера.
- Написать иные программы (обучающие или, возможно, для чтения текста). Пример - часы (показать время с помощью ячейки Брайля).
- Повысить компактность ячейки Брайля: взять подшипники меньшего размера, перекомпоновать сервоприводы (разместить два из них на другой стороне рычагов).
- Попробовать управлять серво с помощью ШИМ контроллера PCA9685
- Создать ячейку с восемью точками (расширенный шрифт Брайля).

4

- Снабдить тренажёр особой клавиатурой из восьми клавиш. Снабдить встроенным динамиком и, возможно, лампочками для зрячего иструктора (индикатор питания и подключения хост-контроллера).
- Предусмотреть в конструкции механизм для автокалибровки ячейки.
- Уделить внимание не техническим аспектам (презентовать проект, возможно, создать видеоклип/сайт проекта).

## Использованные источники

[1] Тренажёр Брайля. Глеб Андреевич Мирошник. [Электронный ресурс]

## http://www.brailletrainer.ru

[2] Microtuators of SMA for Braille display system https://www.

## researchgate.net/publication/232633029_Microtuators_of_

SMA_for_Braille_display_system (https://www.researchgate.net/publication/232633029_Microtuators_of_SMA_for_Braille_display_system)

[3] Electro-Tactile Display with Force Feedback. Hiroyuki Kajimoto, Naoki Kawakami, Taro Maeda and Susumu Tachi: Graduate School of Information Science and Technology, The University of Tokyo. [Электронный ре-
сурс]. http://citeseerx.ist.psu.edu/viewdoc/download?doi=10.1.1.493.2786&rep=rep1&type=pdf (http://citeseerx.ist.psu.edu/viewdoc/download?doi=10.1.1.493.2786&rep=rep1&type=pdf)
[4] Electro-Tactile Display with Tactile Primary Color Approach. Hiroyuki Kajimoto, Naoki Kawakami, Susumu Tachi. Graduate School of Information Science and Technology, The University of Tokyo. [Электронный

## ресурс]. http://files.tachilab.org/publications/intconf2000/

kajimoto200410IROS.pdf (http://files.tachilab.org/publications/intconf2000/kajimoto200410IROS.pdf)

[5] Bristol | Braille | technology | [Электронный | ресурс] | http://

## bristolbraille.co.uk

[6] Refreshable braille reader. John W. Roberts, Oliver T. Slattery, David
W. Kardos. [Электронный ресурс] https://patents.google.com/

## patent/US6776619 (https://patents.google.com/patent/US6776619)

[7] Оценка динамики и прогноз первичной инвалидности в Амурской области вследствие офтальмопатологии. Выдров А. С. [Электрон-
ный | ресурс] | https://cyberleninka.ru/article/v/otsenka-

## dinamiki-i-prognoz-pervichnoy-invalidnosti-v-amurskoy-

oblasti-vsledstvie-oftalmopatologii (https://cyberleninka.ru/article/v/otsenka-dinamiki-i-prognoz-pervichnoy-invalidnosti-v-amurskoy-oblasti-vsledstvie-oftalmopatologii)

5

[8] Актуальность рельефно-точечного шрифта по системе брайля в современном мире. [Электронный ресурс] https://beltiz.by/talking/

## 1068-2013-12-19-11-49-03 (https://beltiz.by/talking/1068-2013-12-19-11-49-03)

[9] М. П. Коновалова, О. Ю. Жарова. Технические средства реабилитации для людей с ограниченными возможностями (на примере опыта работы Калужской областной специальной библиотеки для слепых им. Н. Островского) (окончание). [Электронный

## ресурс] https://cyberleninka.ru/article/v/tehnicheskiesredstva-reabilitatsii-dlya-lyudey-s-ogranichennymivozmozhnostyami-na-primere-opyta-raboty-kaluzhskoy-

oblastnoy-1 (https://cyberleninka.ru/article/v/tehnicheskie-sredstva-reabilitatsii-dlya-lyudey-s-ogranichennymi-vozmozhnostyami-na-primere-opyta-raboty-kaluzhskoy-oblastno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)

6

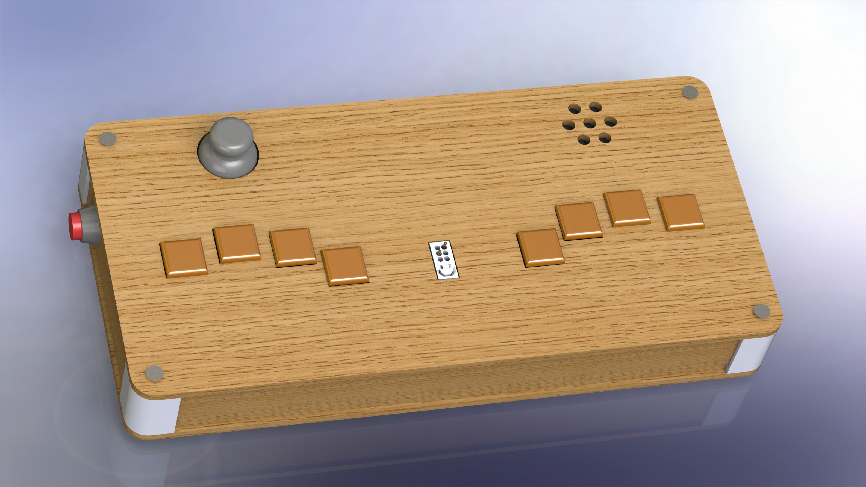
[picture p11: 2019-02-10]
doc/fab_school_closing/render5.JPG

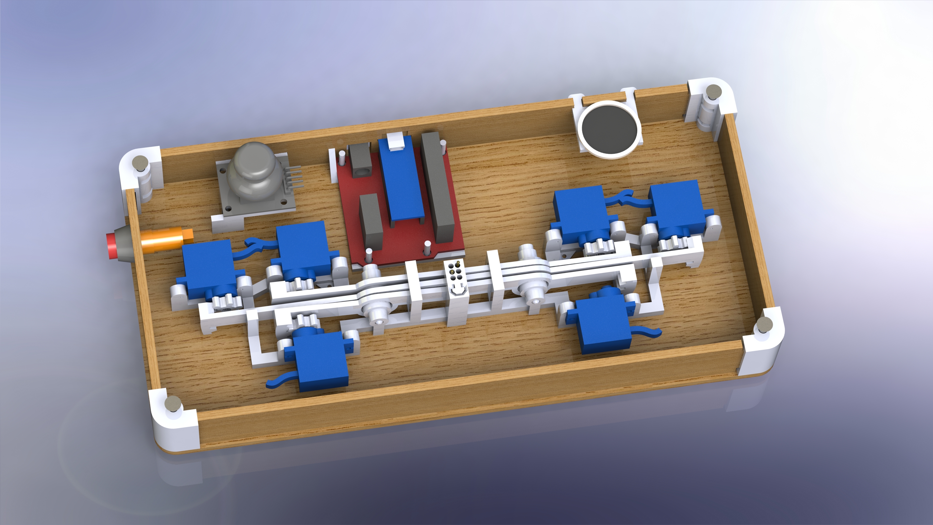
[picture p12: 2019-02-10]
doc/fab_school_closing/render7.JPG

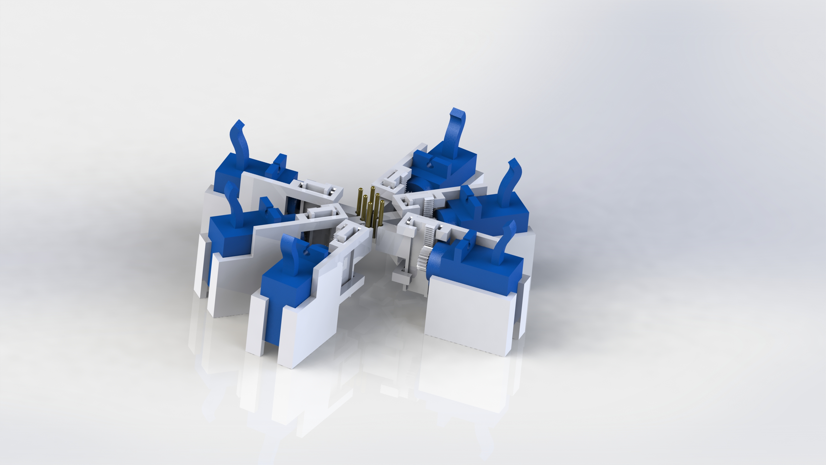
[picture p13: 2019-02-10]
doc/fab_school_closing/render_new.JPG

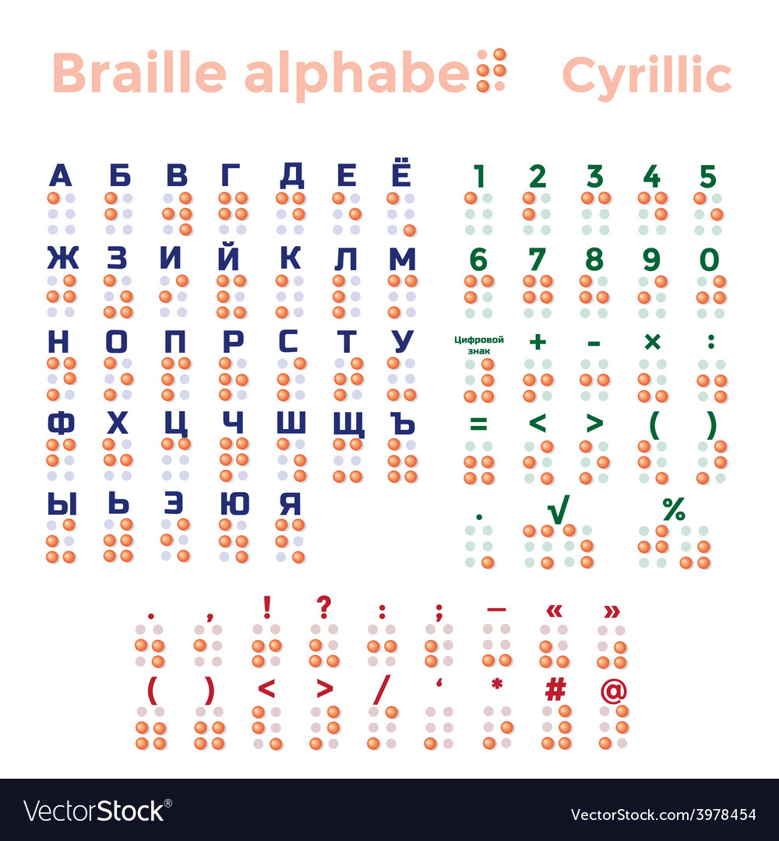
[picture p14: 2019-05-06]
doc/cyrillic-braille-alphabet-punctuation-and-numbers-vector-3978454.jpg

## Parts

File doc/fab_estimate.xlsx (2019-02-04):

Смета проекта "Тренажёр Брайля"
№ п\п | Наименование товара | Источник | Единицы измерения | Кол-во | Цена, руб. | Стоимость, руб. | Примечание
1 | Набор тактовых кнопок 6x6 | https://roboshop.spb.ru/clock-button-set | шт | 1 | 200 | 200
2 | Радиальный подшипник 623ZZ | https://roboshop.spb.ru/623ZZ | шт | 6 | 20 | 120
3 | Arduino Nano Sensor Shield | https://roboshop.spb.ru/nano-multi-shield | шт | 1 | 120 | 120
4 | Arduino Nano V3 | https://roboshop.spb.ru/Arduino-Nano-V3 | шт | 1 | 210 | 210
5 | Кабель mini-USB-BM USB-AM F | http://roboparts.ru/products/kabel-mini-usb-bm-usb-am | шт | 1 | 145 | 145
6 | фанера ФК сорт 2/4 1525х1525х4мм | https://www.maxidom.ru/catalog/fanera/1001088706/ | шт | 1 | 487 | 487
7 | Серводвигатель MG90S | http://roboparts.ru/products/mg90s-towerpro-servoprivod | шт | 4 | 225 | 900
Итого |  |  |  |  |  | 2182

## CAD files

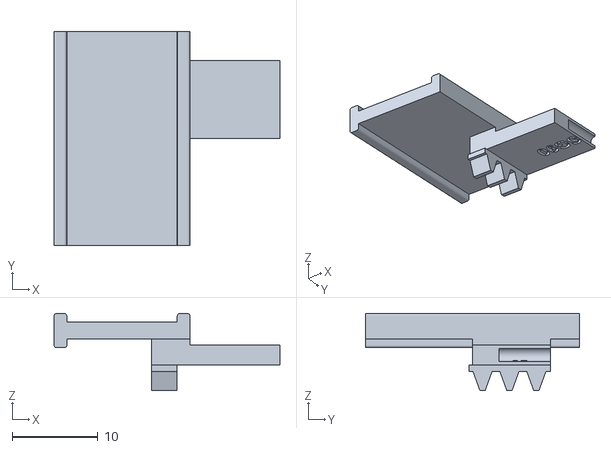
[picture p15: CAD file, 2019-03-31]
parts/stl2/rack_asm_0745.STL
26.4 x 25.0 x 9.00

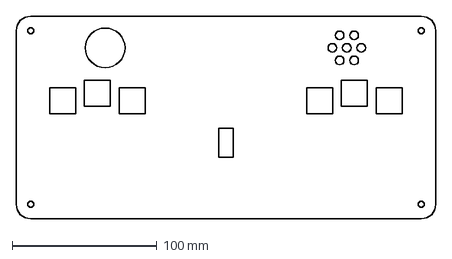
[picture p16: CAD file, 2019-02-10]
parts/dxf/deck_upper+buttons.DXF
290.0 x 140.0 mm

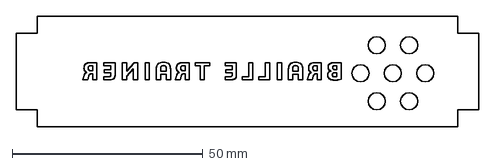
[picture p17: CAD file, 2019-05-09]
parts/dxf2/side-long.DXF
121.0 x 29.0 mm

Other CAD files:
parts/solidworks2/asmx6.SLDASM
parts/sld2_asm/ASM.SLDASM
parts/sld2_asm/expl.SLDASM
parts/solidworks2/asmx6_part_base.SLDASM
parts/solidworks2/gear_asm.SLDASM
parts/solidworks2/rack_asm.SLDASM
parts/solidworks/assembly.SLDASM
parts/sld2_asm/asm_support.SLDASM
parts/solidworks2/asm.SLDASM
parts/solidworks2/asm_button.SLDASM
parts/solidworks/asm_shield.SLDASM
parts/okstop_logo/Emblem.SLDPRT
parts/sld2_asm/usbNest.SLDPRT
parts/solidworks/drumstick.SLDPRT
parts/solidworks2/chocolate2AjacentJoystick.SLDPRT
parts/dxf/deck_lower.DXF
parts/dxf/deck_upper.DXF
parts/dxf/side-1.DXF
parts/dxf/side-back.DXF
parts/dxf/side-long.DXF
parts/dxf2/deck_lower.DXF
parts/dxf2/deck_upper.DXF
parts/dxf2/side-1.DXF
parts/dxf2/side-2-button.DXF
parts/dxf2/side-long-back.DXF
parts/okstop_logo/Emblem.STL
parts/sld2_asm/PWM Shield.SLDPRT
parts/sld2_asm/arch.SLDPRT
parts/sld2_asm/corner_joystick.SLDPRT
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

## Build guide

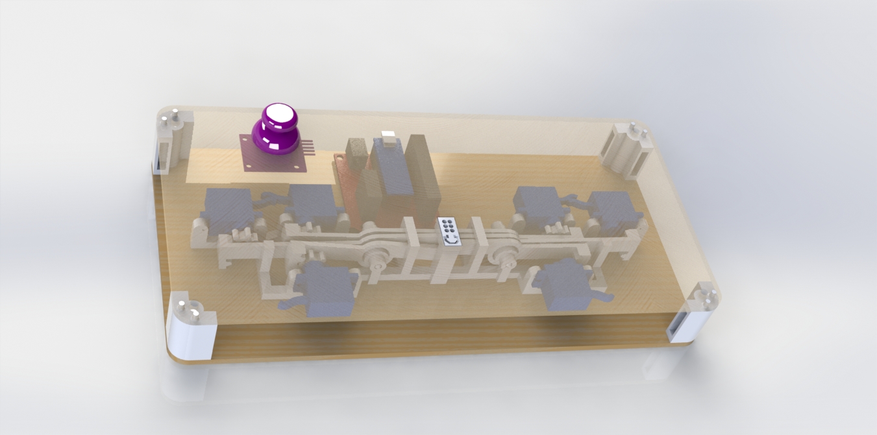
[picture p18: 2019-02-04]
doc/fab_school_intro/pictures/braille_assembly.JPG

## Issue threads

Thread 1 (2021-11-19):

Help to create a new braille device

discapacidad5, 2021-11-19:
Help to create a new braille device

Hi, I don't speak English, I'm using the google translator, I hope they understand me, my language is Spanish

I am developing a braille line with the ardiuno IDE and esp32 I have all the hardware but my problem is precisely that I do not fear how to communicate with the esp32
I have tried to connect the serial monitor of ardiuno and connect the esp32 by bluetooth and in the output of the serial port I get pure question marks and unreadable characters
I would like help to develop the software that would go in the esp32 that exchange data with the devices

my project consists of a very low cost braille display probably anyone can manufacture with less than $ 50 the idea is to create everything and make it available so that anyone can print their own braille display on a 3d printer and added the esp32 card and the driver can make your own braille line I hope someone can help me

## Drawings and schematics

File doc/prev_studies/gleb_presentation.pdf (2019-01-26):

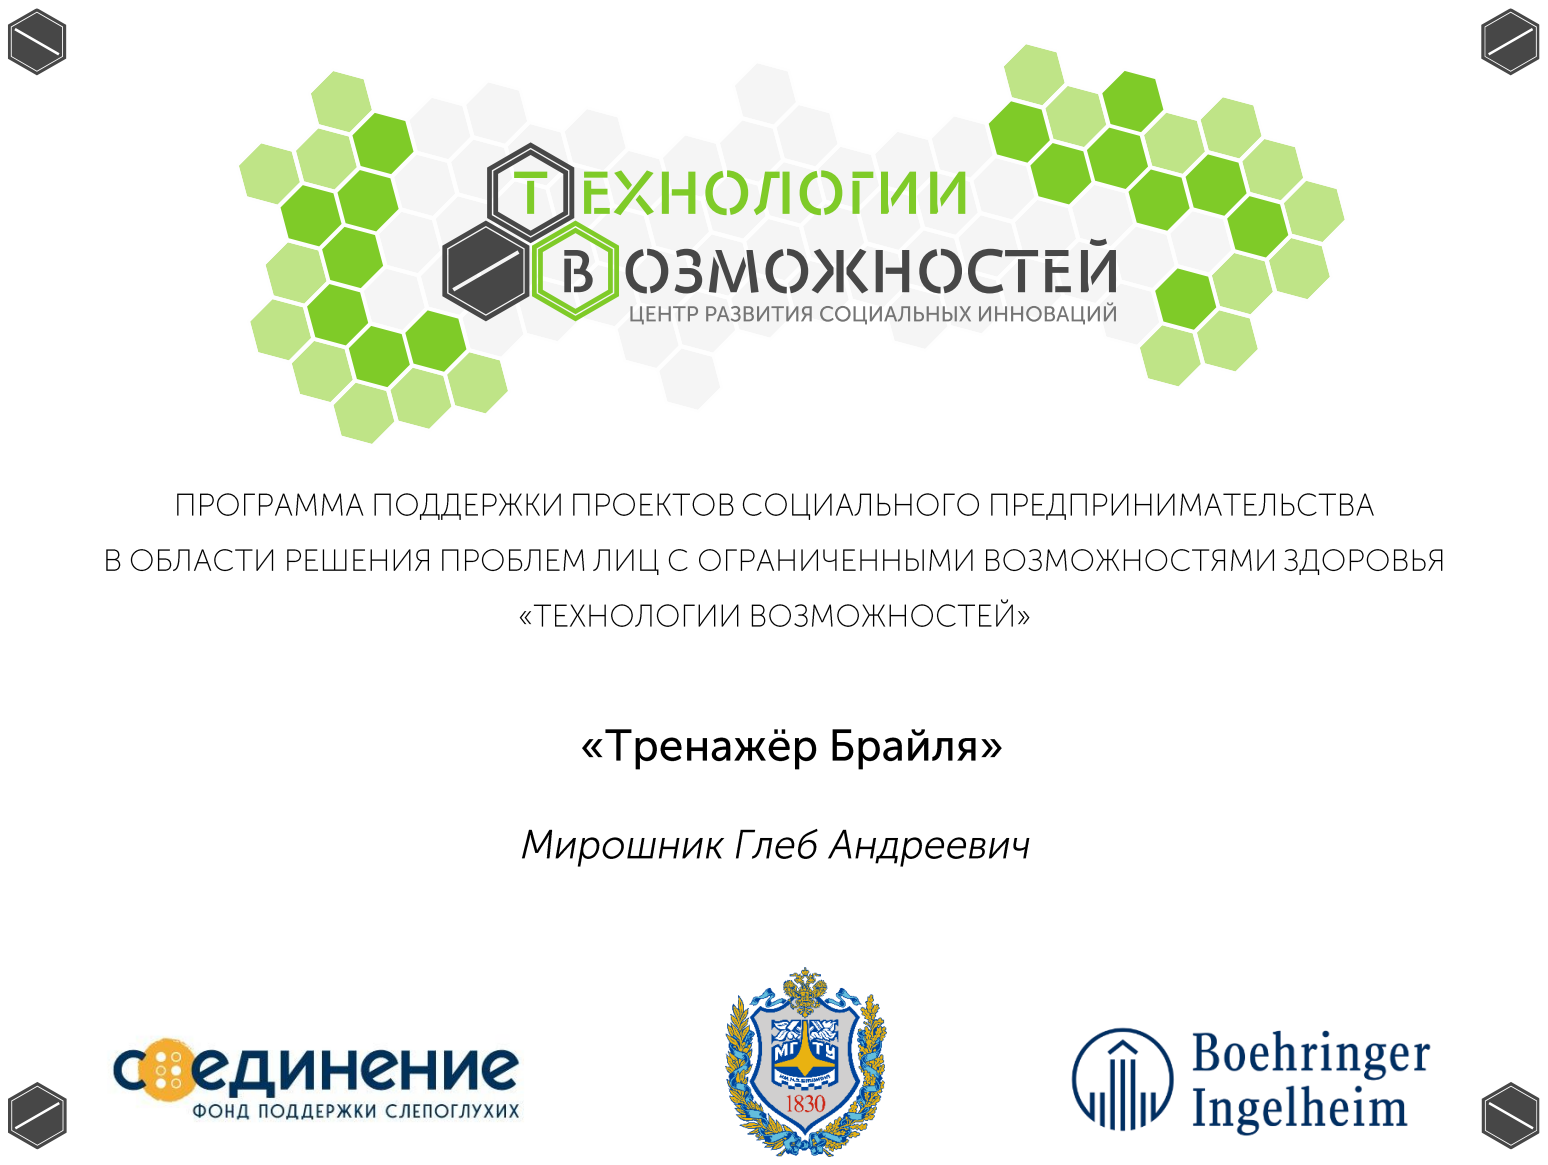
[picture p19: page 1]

•

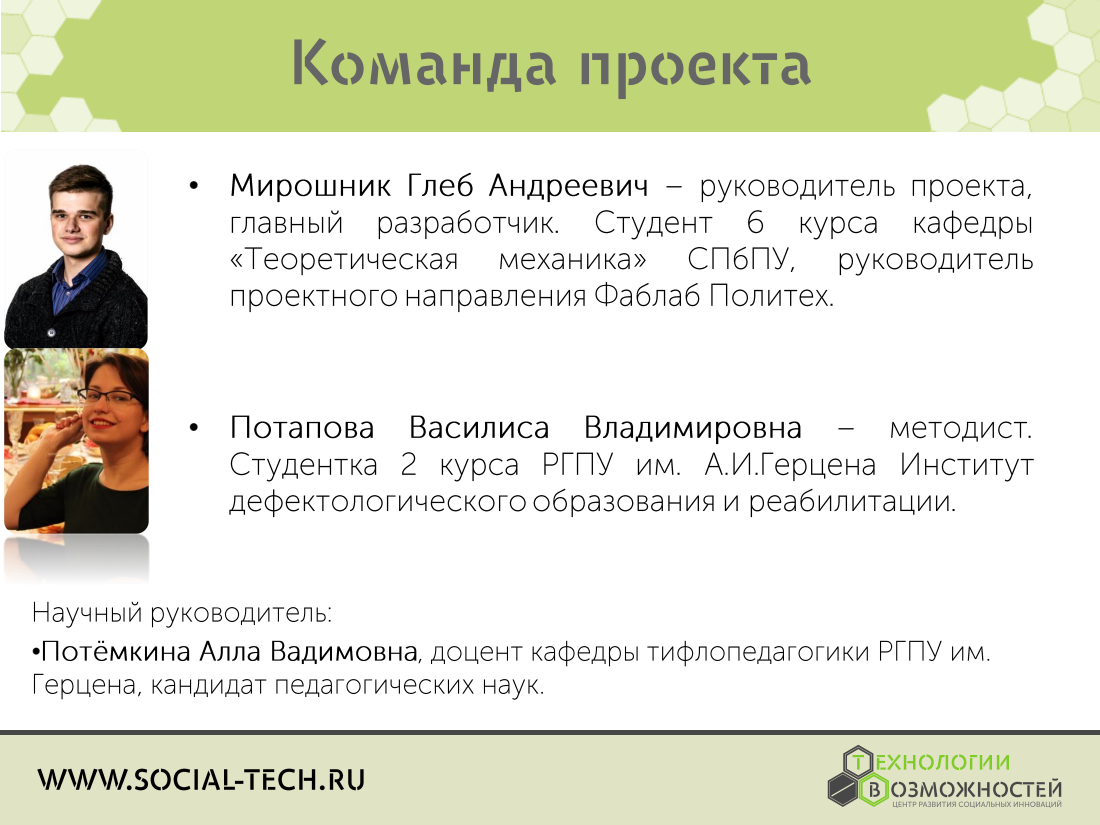
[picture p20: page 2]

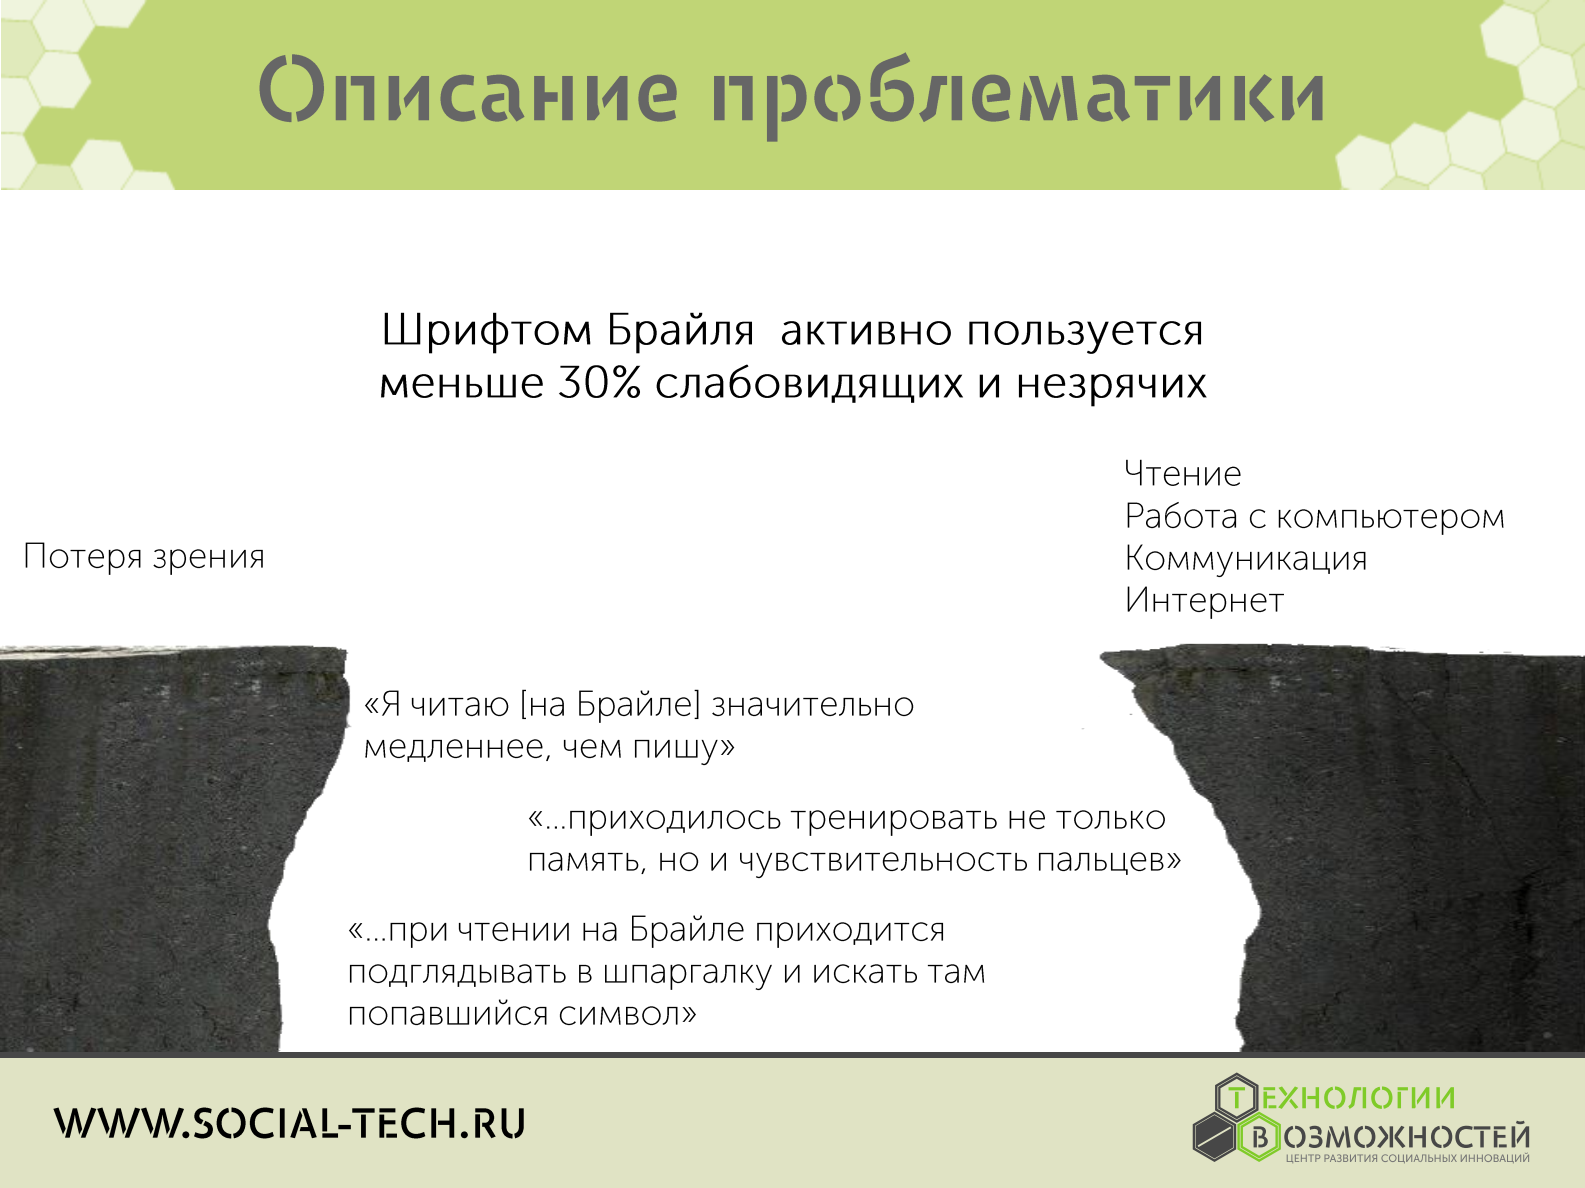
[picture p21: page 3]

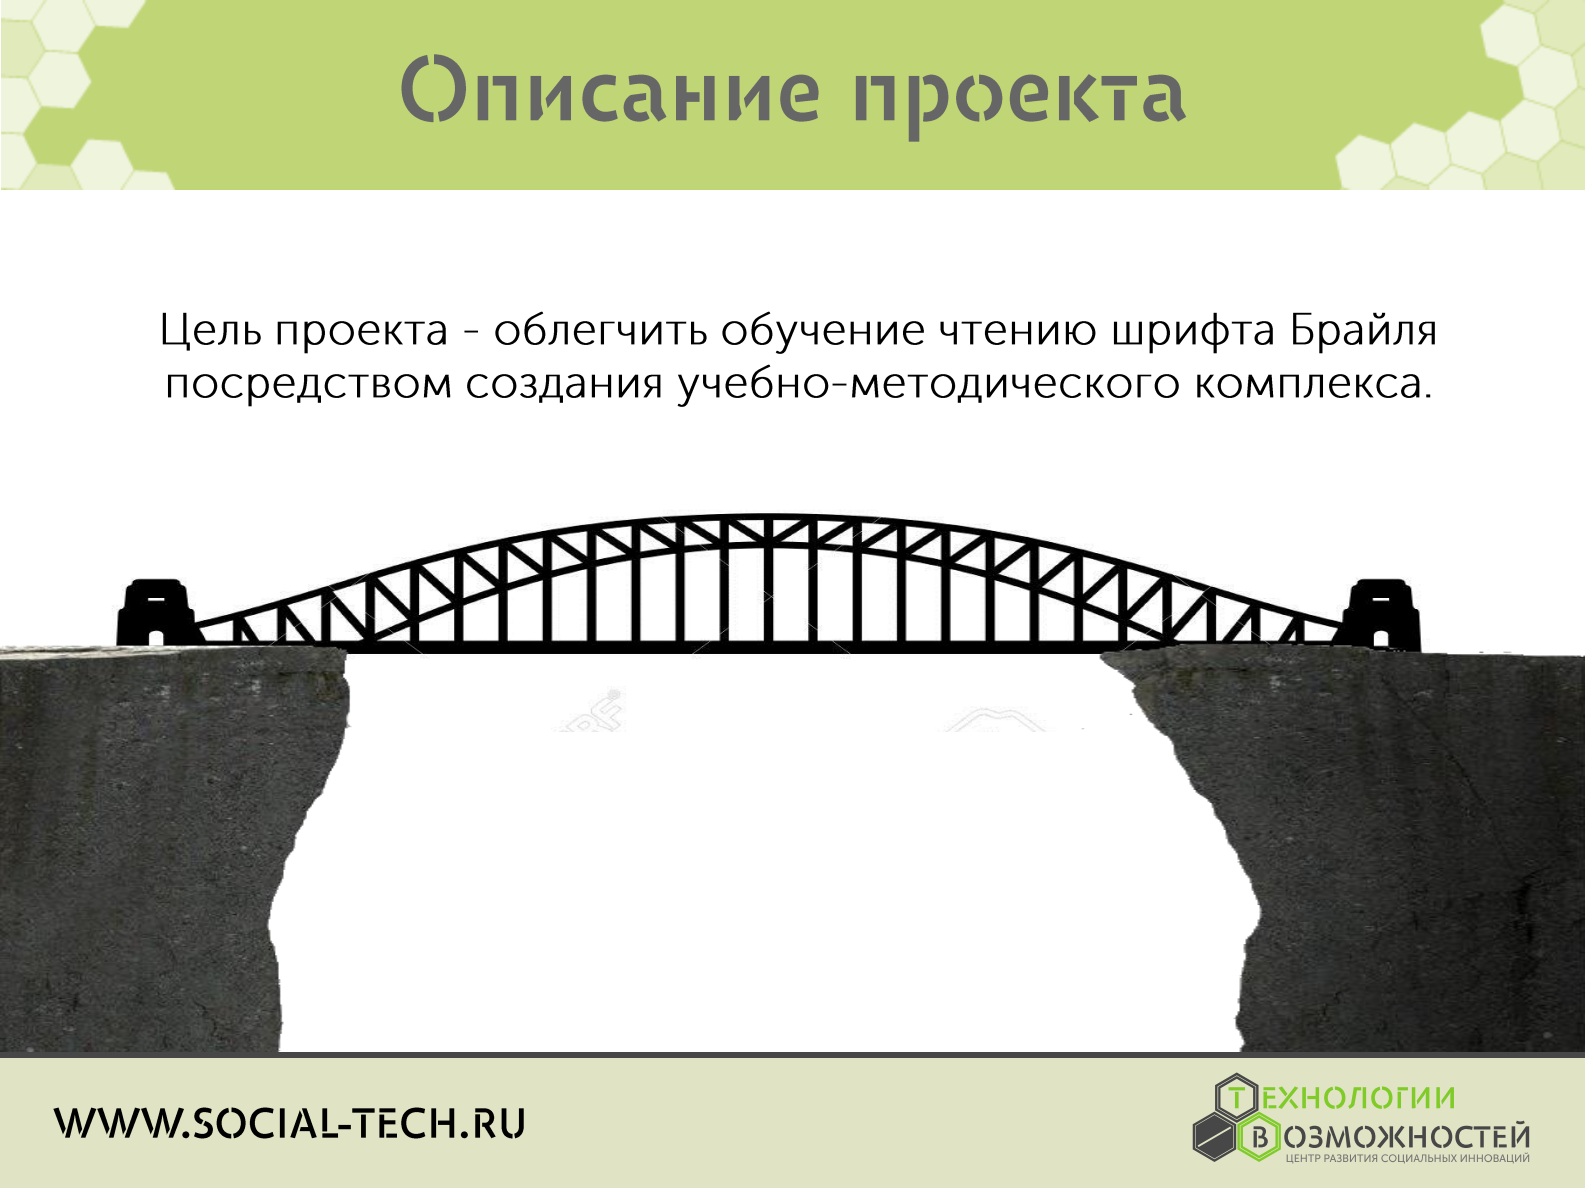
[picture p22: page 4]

•••

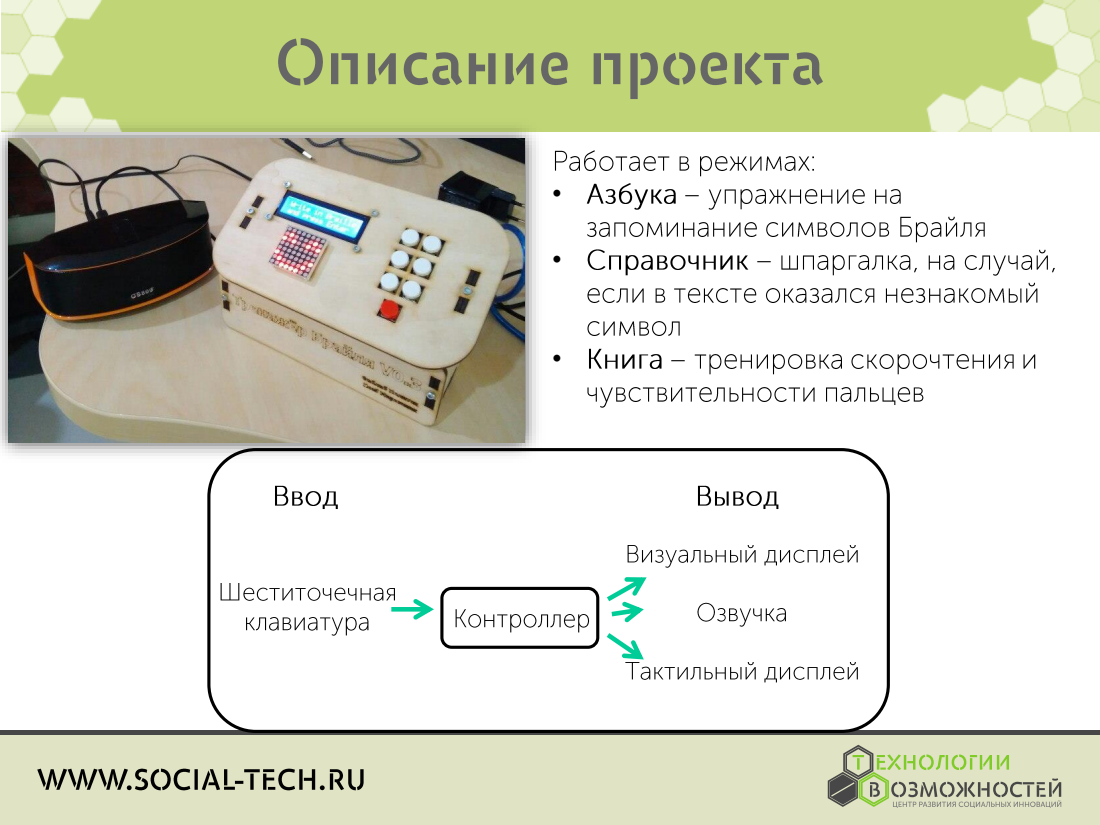
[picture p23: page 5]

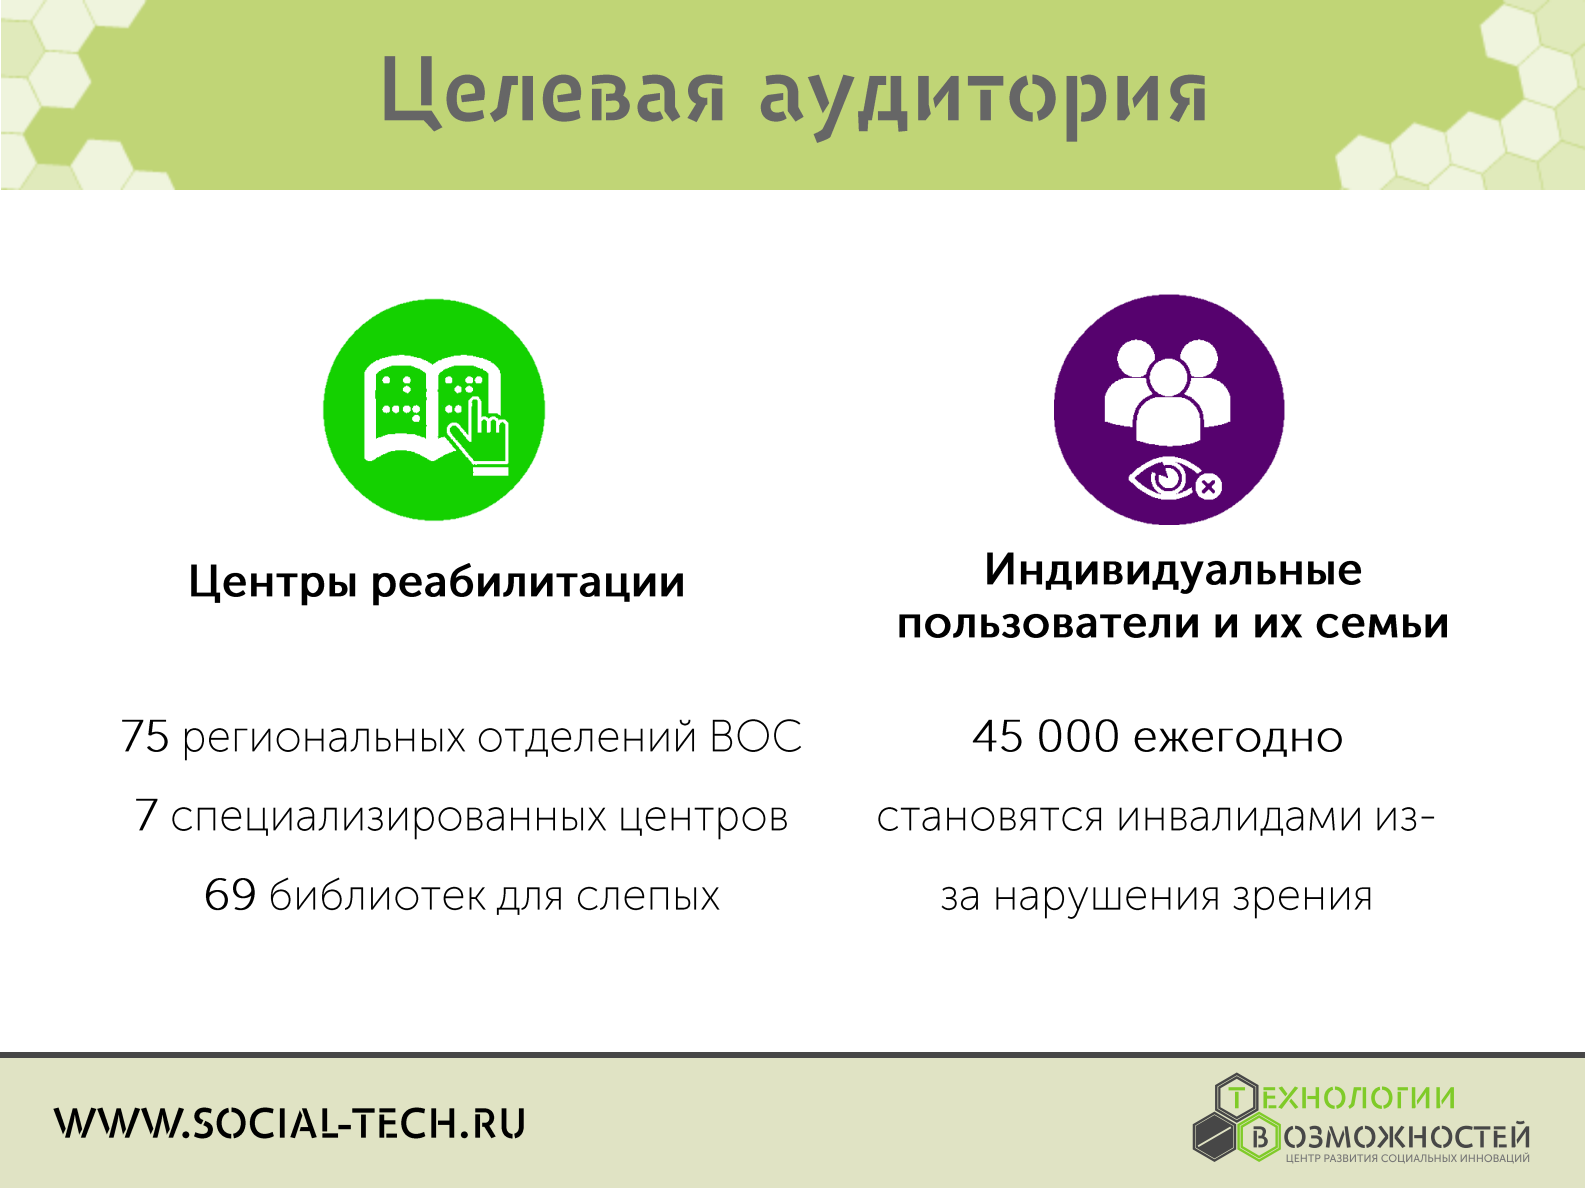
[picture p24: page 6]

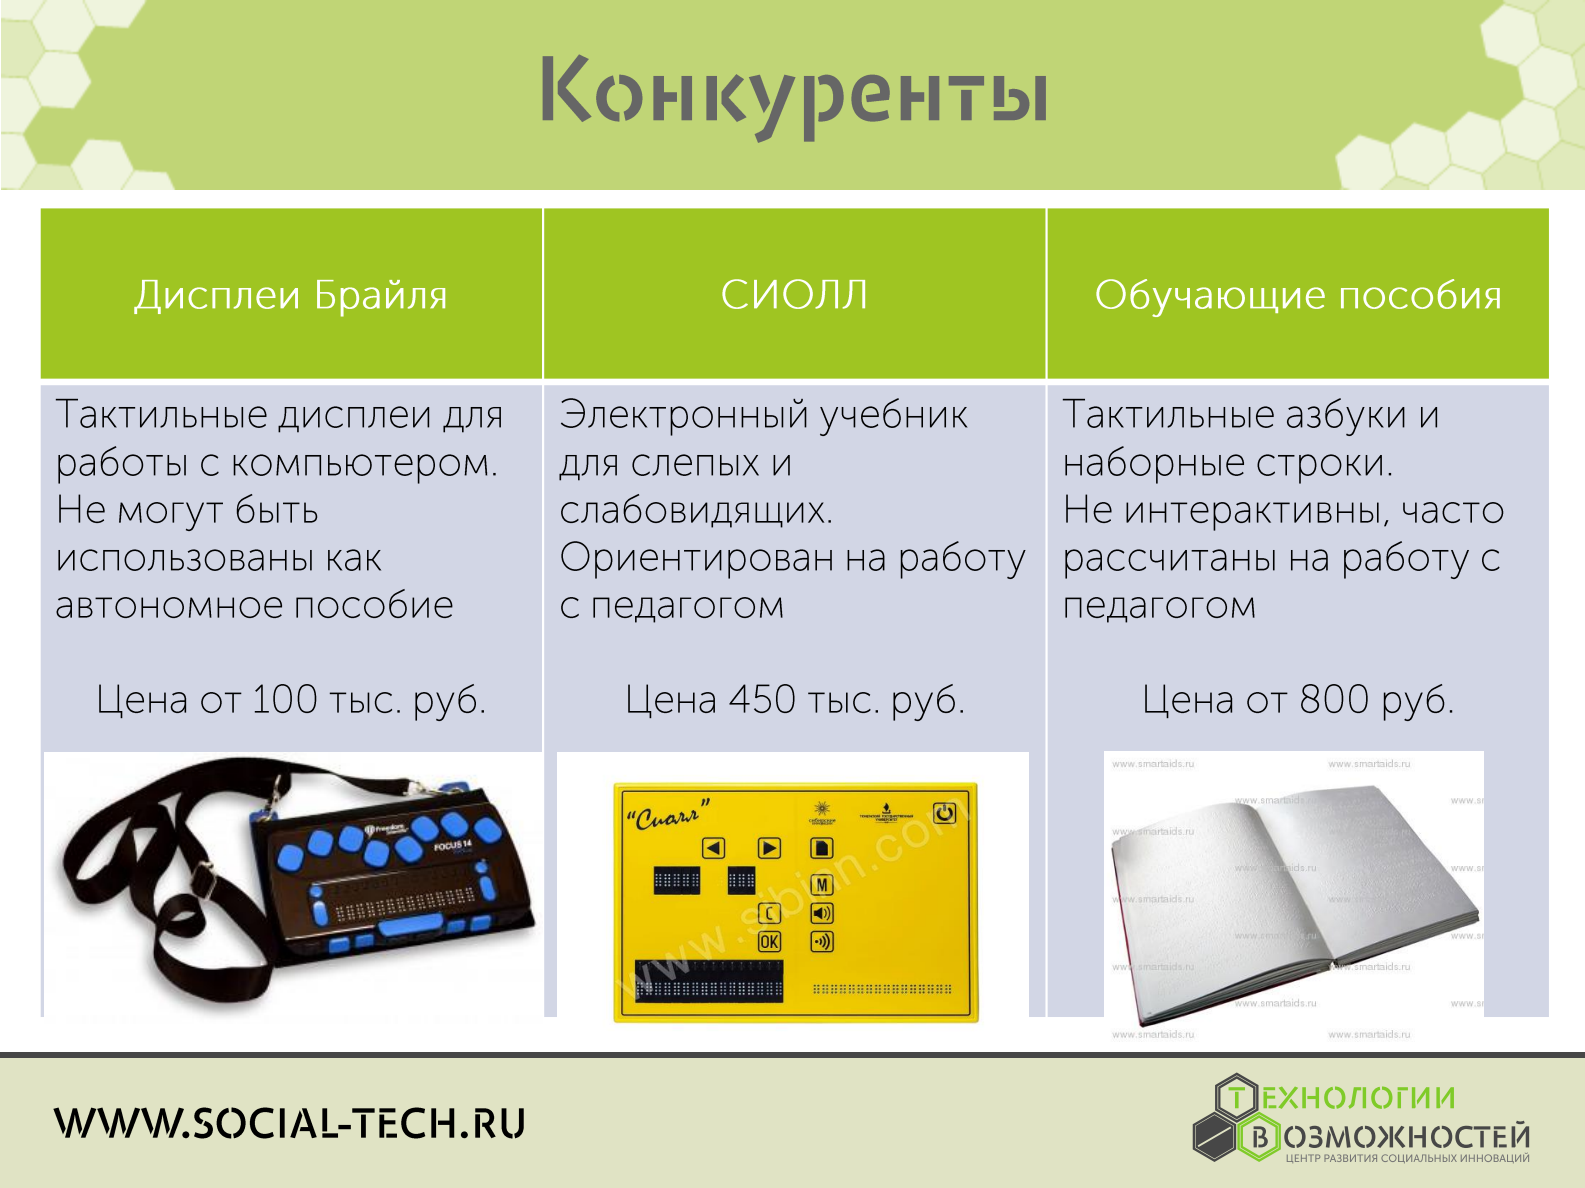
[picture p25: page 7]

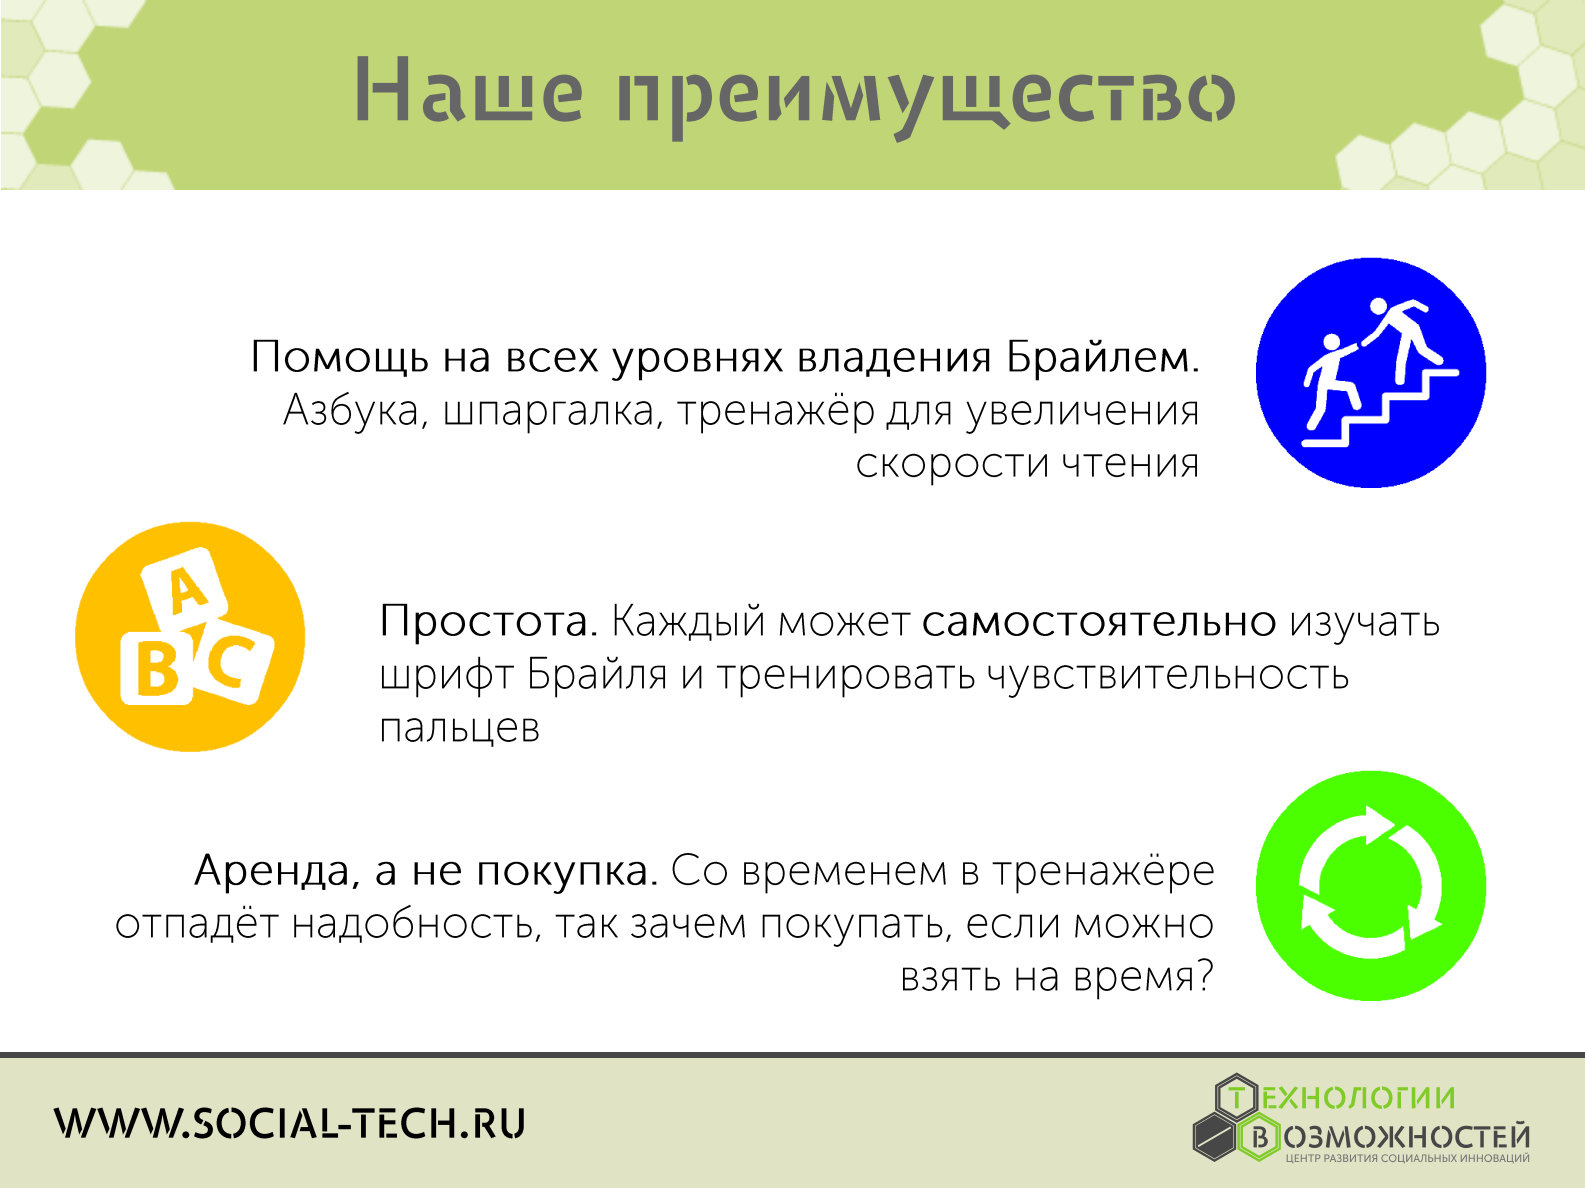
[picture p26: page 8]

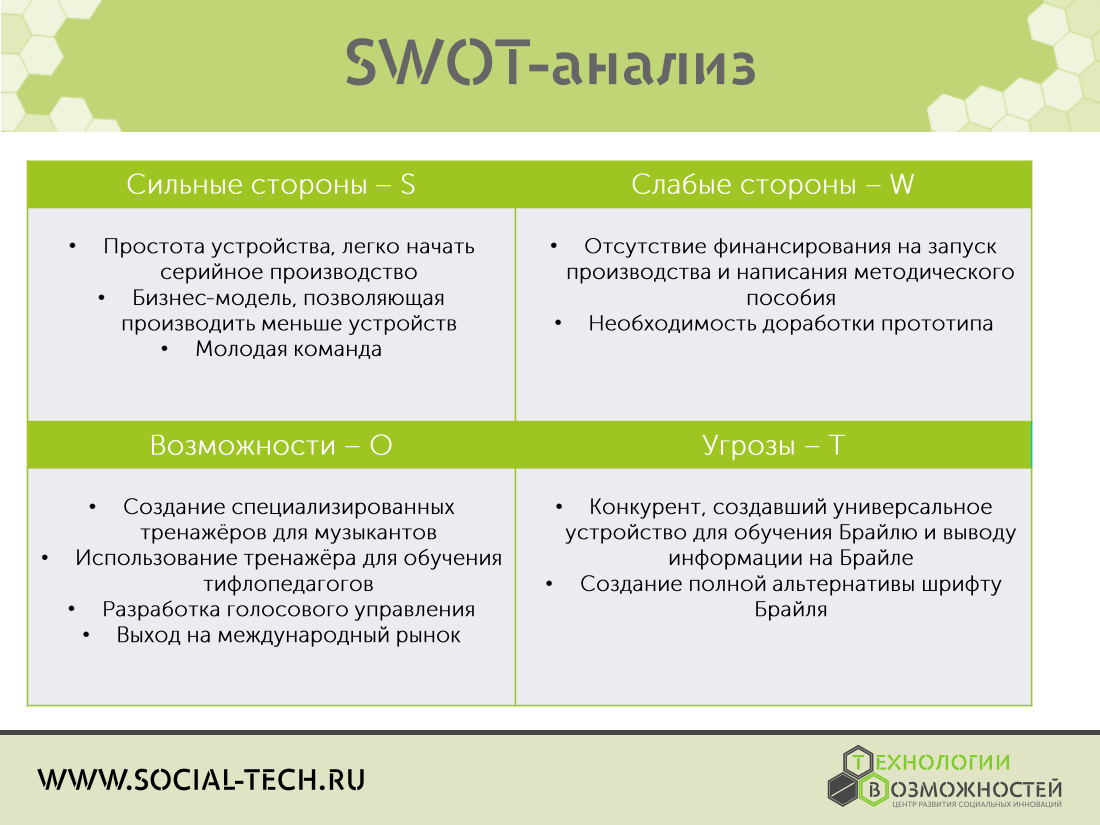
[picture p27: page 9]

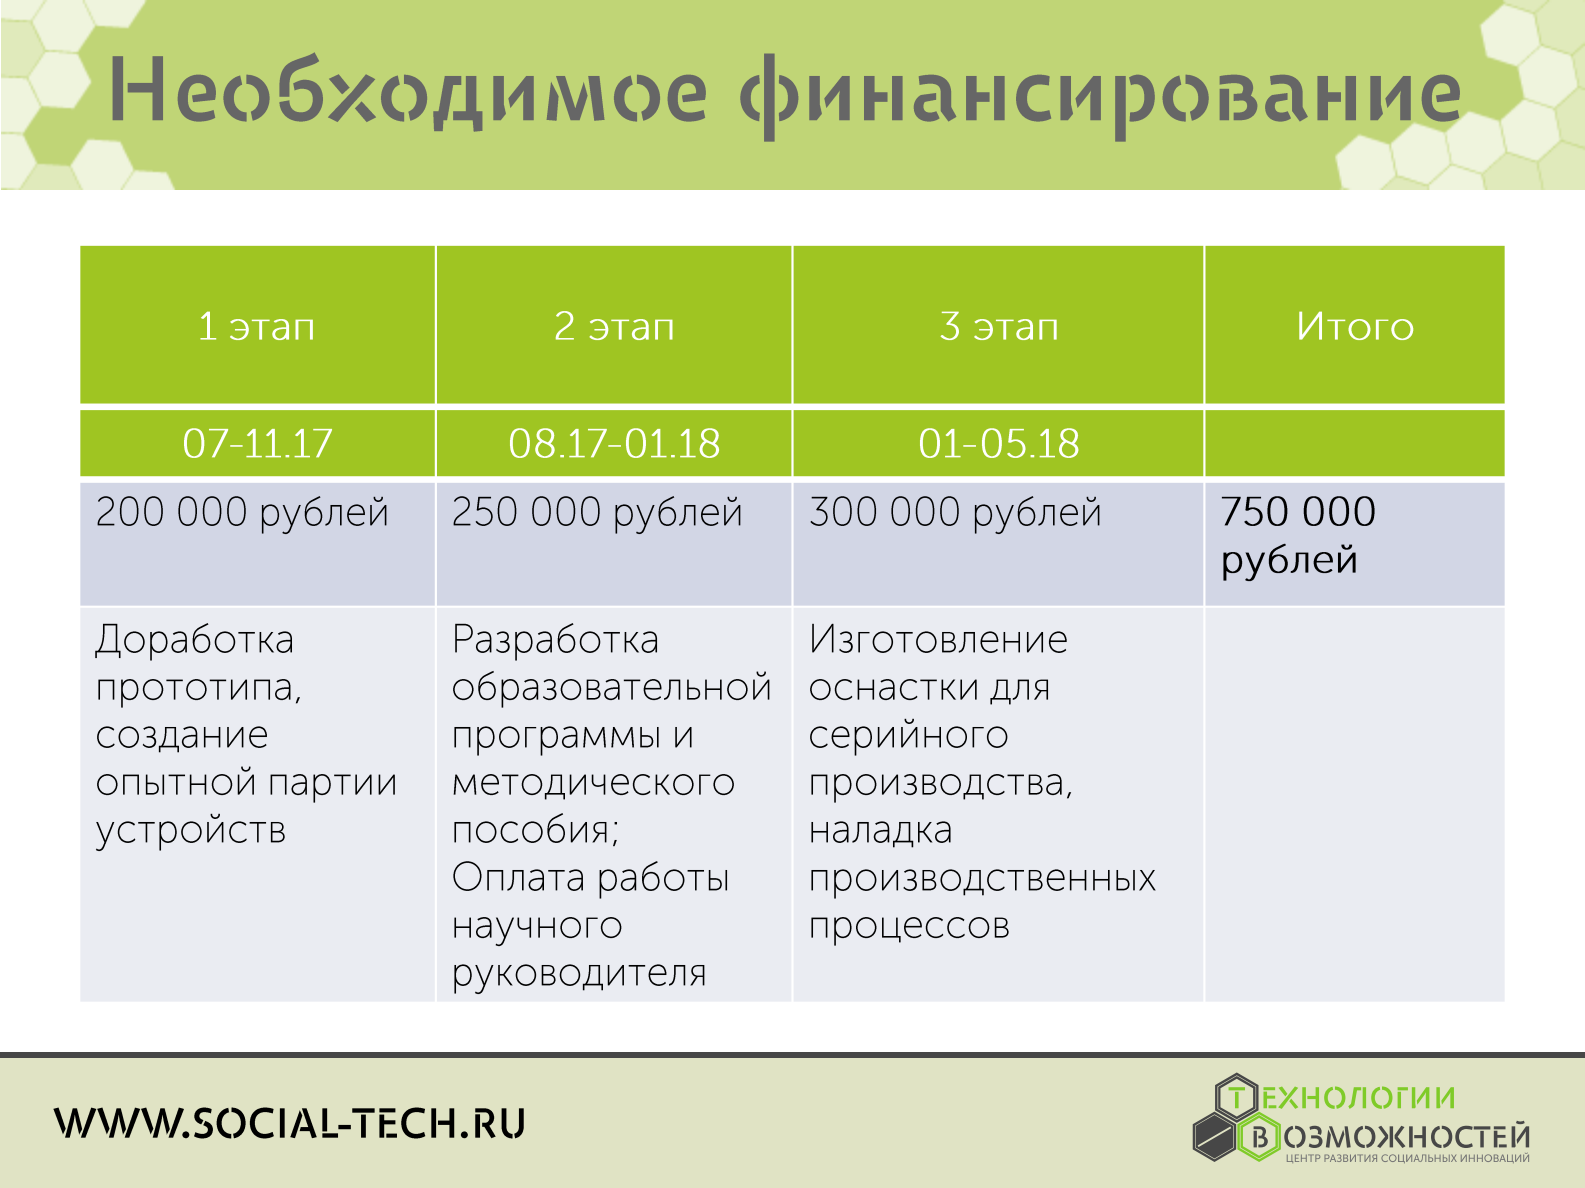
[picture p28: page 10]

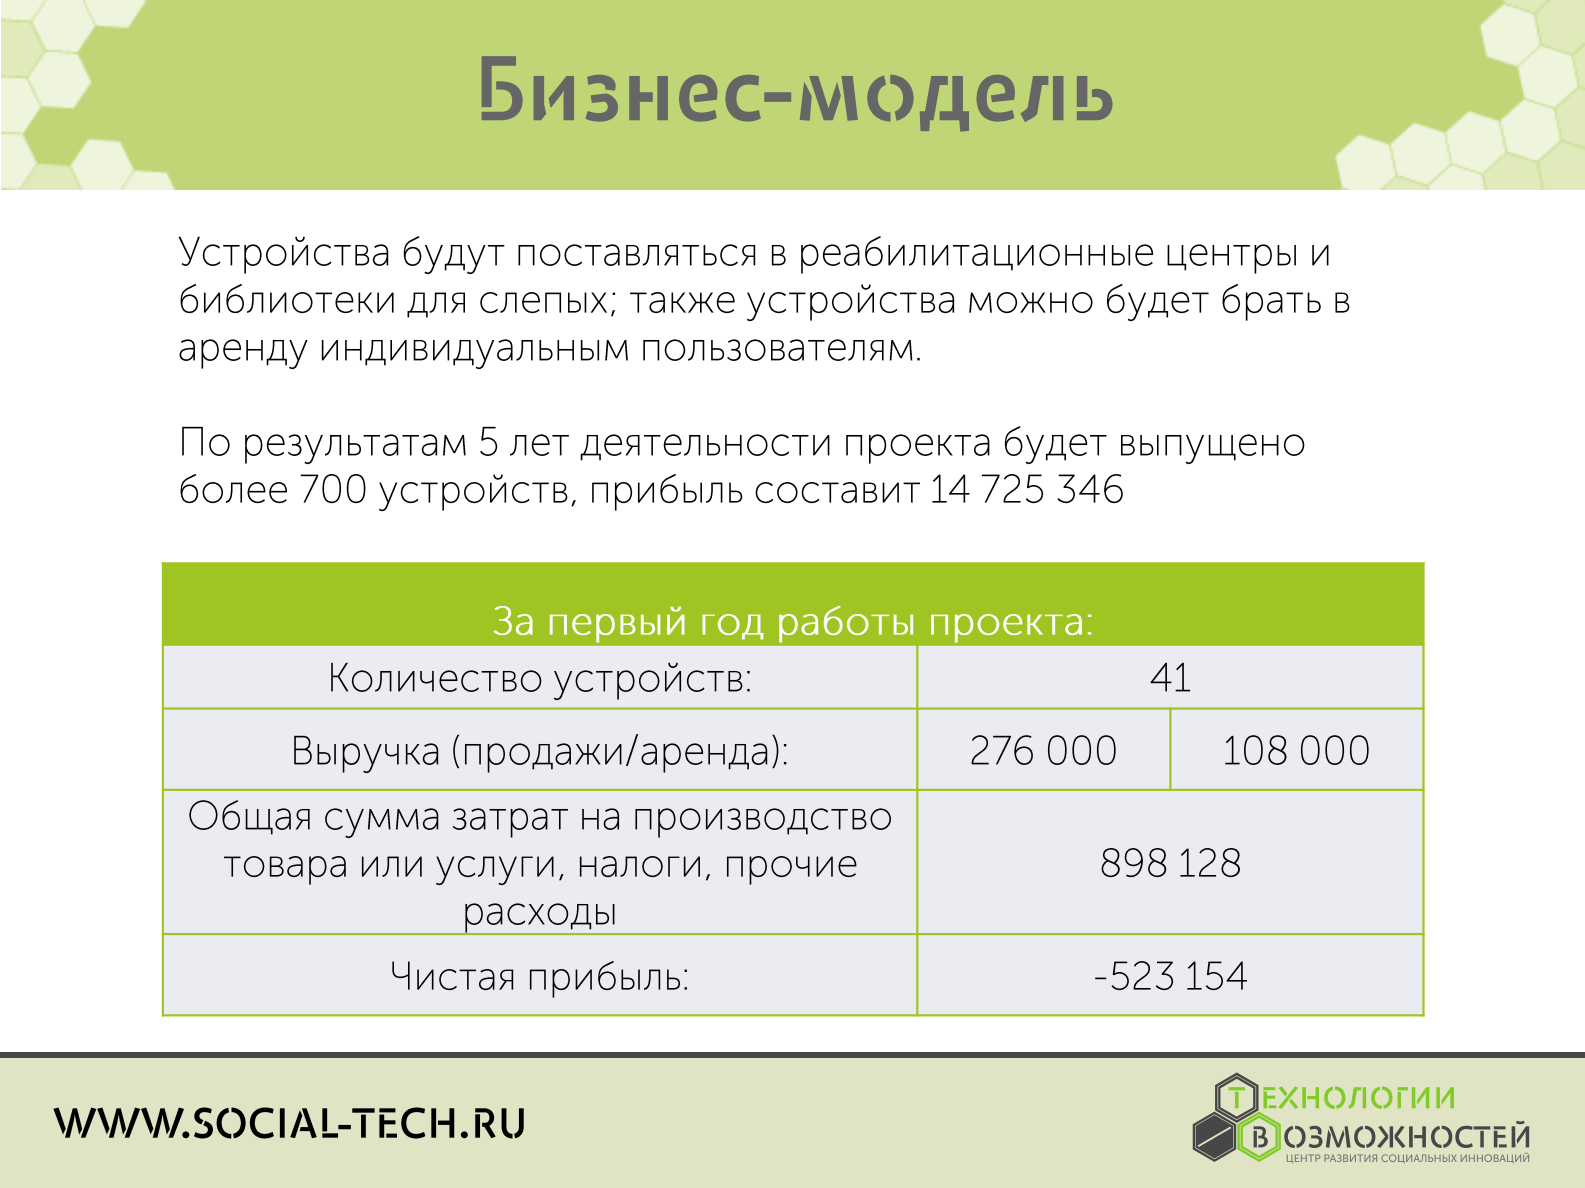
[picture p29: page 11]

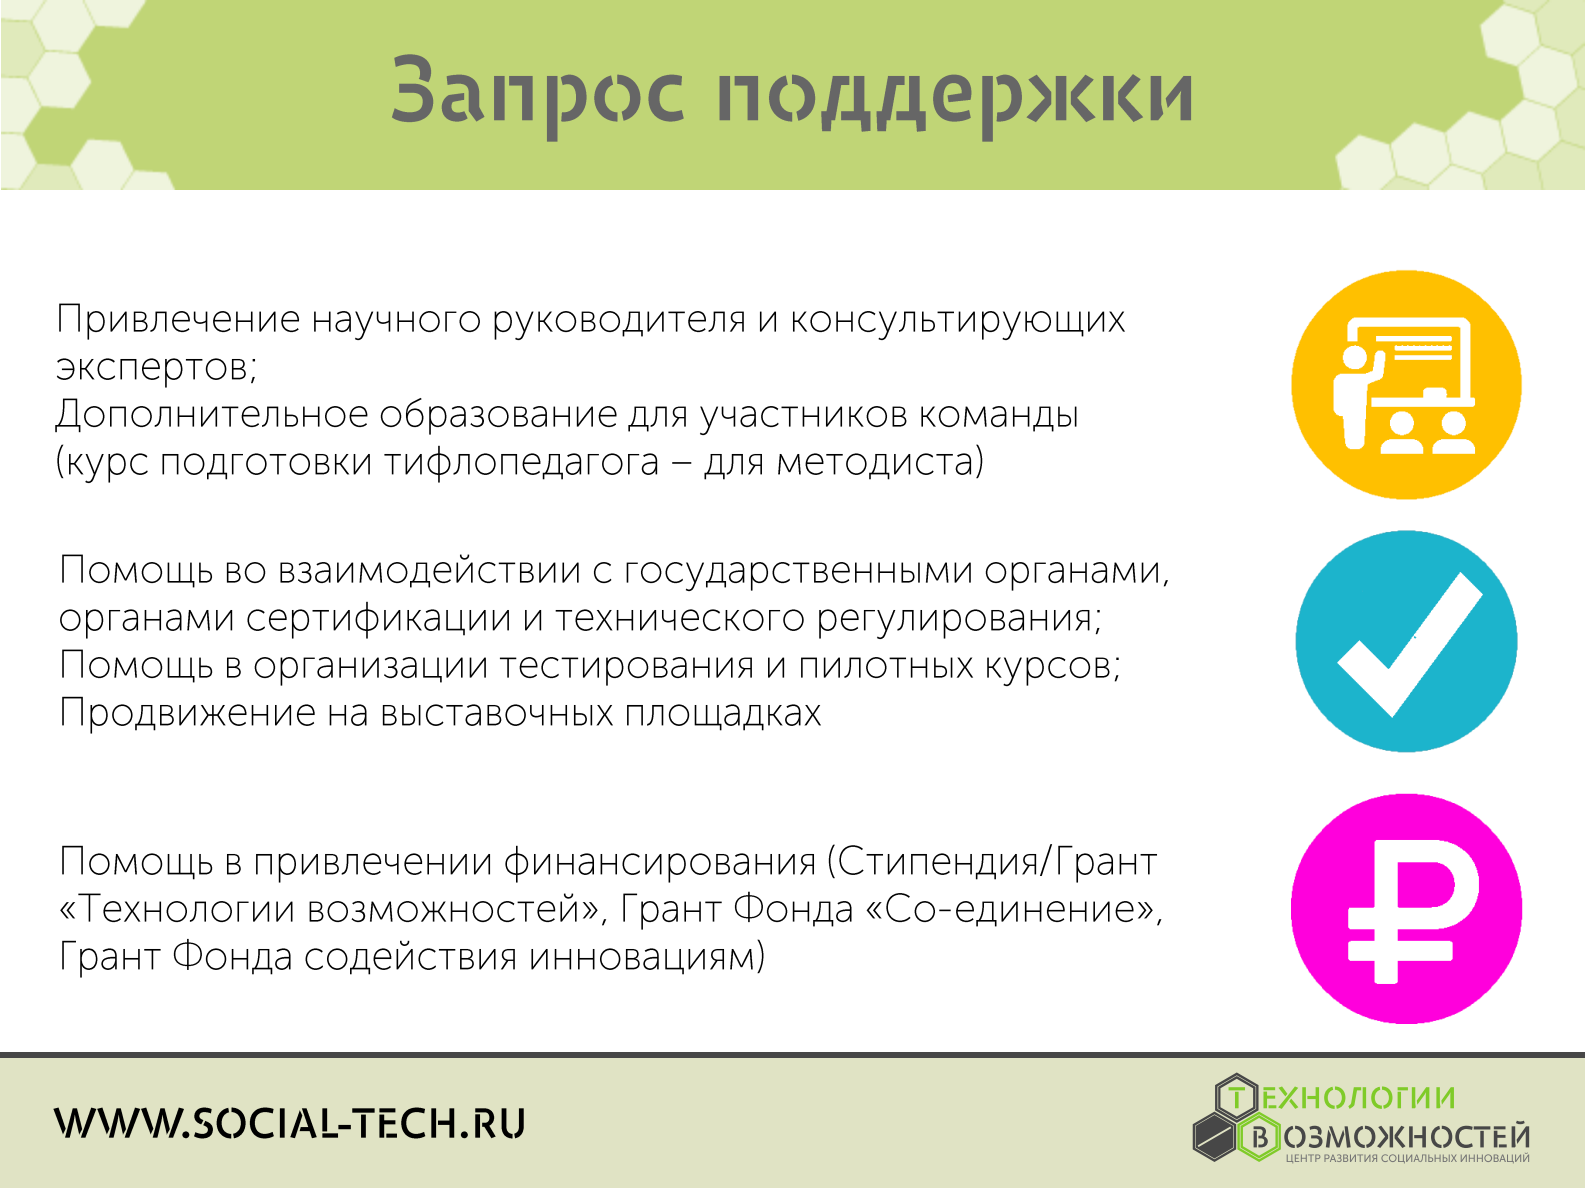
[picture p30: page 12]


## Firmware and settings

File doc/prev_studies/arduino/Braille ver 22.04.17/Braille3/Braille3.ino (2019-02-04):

//We always have to include the library
#include "LedControlMS.h"
#include <Wire.h>
#include <LiquidCrystal_I2C.h>
#include <Adafruit_PWMServoDriver.h>
#include <SoftwareSerial.h>
#include <DFPlayer_Mini_Mp3.h>

Adafruit_PWMServoDriver pwm = Adafruit_PWMServoDriver();

LiquidCrystal_I2C lcd(0x27, 16, 2);
/*
  Now we need a LedControl to work with.
 ***** These pin numbers will probably not work with your hardware *****
  pin 12 is connected to the DataIn
  pin 11 is connected to the CLK
  pin 10 is connected to LOAD
  We have only a single MAX72XX.
*/
LedControl lc = LedControl(12, 10, 11, 1);

#define SERVOMIN  400 // this is the 'minimum' pulse length count (out of 4096)
#define SERVOMAX  450 // this is the 'maximum' pulse length count (out of 4096)
#define rightb 15
#define leftb 16
#define btn1 8
#define btn2 2
#define btn3 3
#define btn4 4
#define btn5 5
#define btn6 6
#define enter 7
uint8_t servonum = 0;
/* here is the data for the characters */
byte nl[8] = {B00000000, B00000000, B00000000, B00000000, B00000000, B00000000, B00000000, B00000000};
byte a[8] = {B00011000, B00100100, B01000010, B01000010, B01111110, B01000010, B01000010, B01000010};
byte b[8] = {B01111110, B01000000, B01000000, B01111100, B01000010, B01000010, B01000010, B01111100};
byte v[8] = {B01111100, B01000010, B01000010, B01111100, B01000010, B01000010, B01000010, B01111100};
byte g[8] = {B01111110, B01000000, B01000000, B01000000, B01000000, B01000000, B01000000, B01000000};
byte d[8] = {B00011000, B00100100, B00100100, B00100100, B00100100, B00111100, B01000010, B01000010};
byte e[8] = {B01111110, B01000000, B01000000, B01111100, B01000000, B01000000, B01000000, B01111110};
byte yo[8] = {B00100100, B00000000, B01111110, B01000000, B01111000, B01000000, B01000000, B01111110};
byte zhe[8] = {B11011011, B01011010, B01111110, B00011000, B00011000, B01111110, B01011010, B11011011};
byte z[8] = {B00011100, B00100010, B00000010, B00001100, B00000010, B00000010, B00100010, B00011100};
byte i[8] = {B01000110, B01000110, B01001010, B01011010, B01011010, B01110010, B01100010, B01000010};
byte j[8] = {B00100100, B00011000, B01000010, B01000110, B01001010, B01010010, B01100010, B01000010};
byte k[8] = {B01000110, B01001000, B01010000, B01100000, B01110000, B01001000, B01000100, B01000010};
byte l[8] = {B00011000, B00100100, B00100100, B01000010, B01000010, B01000010, B10000001, B10000001};
byte m[8] = {B01000010, B01000010, B01100110, B01011010, B01011010, B01000010, B01000010, B01000010};
byte n[8] = {B01000010, B01000010, B01000010, B01111110, B01111110, B01000010, B01000010, B01000010};
byte o[8] = {B00111100, B01000010, B01000010, B01000010, B01000010, B01000010, B01000010, B00111100};
byte p[8] = {B01111110, B01000010, B01000010, B01000010, B01000010, B01000010, B01000010, B01000010};
byte r[8] = {B00111000, B00100100, B00100100, B00111000, B00100000, B00100000, B00100000, B00100000};
byte s[8] = {B00011100, B00100010, B00100010, B00100000, B00100000, B00100010, B00100010, B00011100};
byte t[8] = {B11111111, B01111110, B00011000, B00011000, B00011000, B00011000, B00011000, B00011000};
byte y[8] = {B01000010, B01000010, B01000010, B00111110, B00001100, B00011000, B00110000, B01100000};
byte f[8] = {B01111110, B10011001, B10011001, B10011001, B01111110, B00011000, B00011000, B00011000};
byte x[8] = {B11000011, B01100110, B00111100, B00011000, B00011000, B00111100, B01100110, B11000011};
byte tse[8] = {B01000100, B01000100, B01000100, B01000100, B01000100, B01111100, B00000010, B00000011};
byte ch[8] = {B00100100, B00100100, B00100100, B00111100, B00000100, B00000100, B00000100, B00000100};
byte sh[8] = {B10010010, B10010010, B10010010, B10010010, B10010010, B10010010, B11111110, B00000000};
byte sch[8] = {B10010010, B10010010, B10010010, B10010010, B10010010, B10010010, B11111111, B00000001};
byte tvz[8] = {B01110000, B10010000, B00010000, B00011110, B00010001, B00010001, B00010001, B00011110};
byte ii[8] = {B10000001, B10000001, B10000001, B11110001, B10001001, B10001001, B10001001, B11110001};
byte mz[8] = {B01110000, B00010000, B00010000, B00011110, B00010001, B00010001, B00010001, B00011110};
byte ee[8] = {B01111100, B00000010, B00000010, B01111110, B00000010, B00000010, B00000010, B01111100};
byte u[8] = {B01000110, B01001001, B01001001, B01111001, B01111001, B01001001, B01001001, B01000110};
byte ya[8] = {B00011110, B00100010, B00100010, B00100010, B00011110, B00010010, B00100010, B00100010};
byte smile[8] = {B00000000, B01000010, B10100101, B00000000, B00000000, B10000001, B01000010, B00111100};
byte frown[8] = {B00000000, B00000000, B11100111, B00000000, B00000000, B00000000, B01111110, B10000001};
byte dntlook[8] = {B00011000, B00100100, B00111100, B00100100, B00100100, B01100110, B11100111, B01100110};

bool ab[6] = {true, false, false, false, false, false};
bool bb[6] = {true, true, false, false, false, false};
bool vb[6] = {false, true, false, true, true, true};
bool gb[6] = {true, true, false, true, true, false};
bool db[6] = {true, false, false, true, true, false};
bool eb[6] = {true, false, false, false, true, false};
bool yob[6] = {true, false, false, false, false, true};
bool zheb[6] = {false, true, false, true, true, false};
bool zb[6] = {true, false, true, false, true, true};
bool ib[6] = {false, true, false, true, false, false};
bool jb[6] = {true, true, true, true, false, true};
bool kb[6] = {true, false, true, false, false, false};
bool lb[6] = {true, true, true, false, false, false};
bool mb[6] = {true, false, true, true, false, false};
bool nb[6] = {true, false, true, true, true, false};
bool ob[6] = {true, false, true, false, true, false};
bool pb[6] = {true, true, true, true, false, false};
bool rb[6] = {true, true, true, false, true, false};
bool sb[6] = {false, true, true, true, false, false};
bool tb[6] = {false, true, true, true, true, false};
bool yb[6] = {true, false, true, false, false, true};
bool fb[6] = {true, true, false, true, false, false};
bool xb[6] = {true, true, false, false, true, false};
bool tseb[6] = {true, false, false, true, false, false};
bool chb[6] = {true, true, true, true, true, false};
bool shb[6] = {true, false, false, false, true, true};
bool schb[6] = {true, false, true, true, false, true};
bool tvzb[6] = {true, true, true, false, true, true};
bool iib[6] = {false, true, true, true, false, true};
bool mzb[6] = {false, true, true, true, true, true};
bool eeb[6] = {false, true, false, true, false, true};
bool ub[6] = {true, true, false, false, true, true};
bool yab[6] = {true, true, false, true, false, true};
bool button [6] = {false, false, false, false, false, false};
int number;
int mode = 3;



/* we always wait a bit between updates of the display */
unsigned long delaytime = 300;



/*
  This method will display the characters for the
  word "Arduino" one after the other on the matrix.
  (you need at least 5x7 leds to see the whole chars)
*/
//Function to control LED depending on number of symbol
void parce(int num)
{

  switch (num)
  {
    case 0:
    { for (int row = 0; row < 8; row++) {
          lc.setRow(0, row, nl[row]);
        }
      }
      break;
    case 1:
    { for (int row = 0; row < 8; row++) {
          lc.setRow(0, row, a[row]);
        }
      }

      break;
    case 2:
    { for (int row = 0; row < 8; row++) {
          lc.setRow(0, row, b[row]);
        }

      }
      break;
    case 3:
    { for (int row = 0; row < 8; row++) {
          lc.setRow(0, row, v[row]);
        }
      }
      break;
    case 4:
    { for (int row = 0; row < 8; row++) {
          lc.setRow(0, row, g[row]);
        }
      }
      break;
    case 5:
    { for (int row = 0; row < 8; row++) {
          lc.setRow(0, row, d[row]);
        }
      }
      break;
    case 6:
    { for (int row = 0; row < 8; row++) {
          lc.setRow(0, row, e[row]);
        }
      }
      break;
    case 7:
    { for (int row = 0; row < 8; row++) {
          lc.setRow(0, row, yo[row]);
        }
      }
      break;
    case 8:
    { for (int row = 0; row < 8; row++) {
          lc.setRow(0, row, zhe[row]);
        }
      }
      break;
    case 9:
    { for (int row = 0; row < 8; row++) {
          lc.setRow(0, row, z[row]);
        }
      }
      break;
    case 10:
    { for (int row = 0; row < 8; row++) {
          lc.setRow(0, row, i[row]);
        }
      }
      break;
    case 11:
    { for (int row = 0; row < 8; row++) {
          lc.setRow(0, row, j[row]);
        }
      }
    case 12:
    { for (int row = 0; row < 8; row++) {
          lc.setRow(0, row, k[row]);
        }
      }
      break;
    case 13:
    { for (int row = 0; row < 8; row++) {
          lc.setRow(0, row, l[row]);
        }
      }
      break;
    case 14:
    { for (int row = 0; row < 8; row++) {
          lc.setRow(0, row, m[row]);
        }
      }
      break;
    case 15:
    { for (int row = 0; row < 8; row++) {
          lc.setRow(0, row, n[row]);
        }
      }
      break;
    case 16:
    { for (int row = 0; row < 8; row++) {
          lc.setRow(0, row, o[row]);
        }
      }
      break;
    case 17:
    { for (int row = 0; row < 8; row++) {
          lc.setRow(0, row, p[row]);
        }
      }
      break;
    case 18:
    { for (int row = 0; row < 8; row++) {
          lc.setRow(0, row, r[row]);
        }
      }
      break;
    case 19:
    { for (int row = 0; row < 8; row++) {
          lc.setRow(0, row, s[row]);
        }
      }
    case 20:
    { for (int row = 0; row < 8; row++) {
          lc.setRow(0, row, t[row]);
        }
      }
      break;
    case 21:
    { for (int row = 0; row < 8; row++) {
          lc.setRow(0, row, y[row]);
        }
      }
      break;
    case 22:
    { for (int row = 0; row < 8; row++) {
          lc.setRow(0, row, f[row]);
        }
      }
      break;
    case 23:
    { for (int row = 0; row < 8; row++) {
          lc.setRow(0, row, x[row]);
        }
      }
      break;
    case 24:
    { for (int row = 0; row < 8; row++) {
          lc.setRow(0, row, tse[row]);
        }
      }
      break;
    case 25:
    { for (int row = 0; row < 8; row++) {
          lc.setRow(0, row, ch[row]);
        }
      }
    case 26:
    { for (int row = 0; row < 8; row++) {
          lc.setRow(0, row, sh[row]);
        }
      }
      break;
    case 27:
    { for (int row = 0; row < 8; row++) {
          lc.setRow(0, row, sch[row]);
        }
      }
      break;
    case 28:
    { for (int row = 0; row < 8; row++) {
          lc.setRow(0, row, tvz[row]);
        }
      }
      break;
    case 29:
    { for (int row = 0; row < 8; row++) {
          lc.setRow(0, row, ii[row]);
        }
      }
      break;
    case 30:
    { for (int row = 0; row < 8; row++) {
          lc.setRow(0, row, mz[row]);
        }
      }
      break;
    case 31:
    { for (int row = 0; row < 8; row++) {
          lc.setRow(0, row, ee[row]);
        }
      }
      break;
    case 32:
    { for (int row = 0; row < 8; row++) {
          lc.setRow(0, row, u[row]);
        }
      }
      break;
    case 33:
    { for (int row = 0; row < 8; row++) {
          lc.setRow(0, row, ya[row]);
        }
      }
      break;
    case 34:
    { for (int row = 0; row < 8; row++) {
          lc.setRow(0, row, smile[row]);
        }
      }
      break;
    case 35:
    { for (int row = 0; row < 8; row++) {
          lc.setRow(0, row, frown[row]);
        }
      }
      break;
    case 36:
    { for (int row = 0; row < 8; row++) {
          lc.setRow(0, row, dntlook[row]);
        }
      }
      break;
    case 37:
      {
      }
      break;
    case 38:
      {
      }
      break;
    case 39:
      {
      }
      break;
    case 40:
      {
      }
      break;
  }

}
//Function to control motors depending on nubmer of symbol
void parce2(int num)
{
  for (int servo = 0; servo < 6; servo++)
  { Serial.println(servonum);
    for (uint16_t pulselen = SERVOMAX; pulselen > SERVOMIN; pulselen--)
    {
      pwm.setPWM(servo, 0, pulselen);
    }
  }
  delay(300);
  switch (num)
  {
    case 0:
      {
      }
      break;
    case 1:
      {
        { for (int servo = 0; servo < 6; servo++)
          {
            if (ab[servo])
            { for (uint16_t pulselen = SERVOMIN; pulselen < SERVOMAX; pulselen++)
              {
                pwm.setPWM(servo, 0, pulselen);
              }
            }
          }
        }
      }
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
void loop() {
  /*
    lc.setRow(0, 0, 0);
    lc.setRow(0, 1, 0);
    lc.setRow(0, 2, 0);
    lc.setRow(0, 3, 0);
    lc.setRow(0, 4, 0);
    lc.setRow(0, 5, 0);
    lc.setRow(0, 6, 0);
    lc.setRow(0, 7, 0);
    lc.setRow(0, 8, 0);

    delay(delaytime);
    parce(16);
     delay(delaytime*4);
  */
  /*  for (uint16_t pulselen = SERVOMIN; pulselen < SERVOMAX; pulselen++) {
      pwm.setPWM(servonum, 0, pulselen);
    }

    delay(500);
    for (uint16_t pulselen = SERVOMAX; pulselen > SERVOMIN; pulselen--) {
      pwm.setPWM(servonum, 0, pulselen);
    }

    delay(500);

    servonum ++;

    if (servonum > 5) servonum = 0;

  */

  // glebkryt();
/*  if (mode == 1) {
    mode1();
  };
  if (mode == 3) {
    mode3();
  };
  */
/*
  if (digitalRead (rightb) == HIGH)
  { number++;
    if (number == 34) {
      number = 1;
    };
    parce(number);
    parce2(number);
    delay(300);
    Serial.println(number);
  };
  if (digitalRead (leftb) == HIGH)
  { number--;
    if (number == 0) {
      number = 33;
    };
    parce(number);
    parce2(number);
    delay(300);
    Serial.println(number);
  };
*/
mode3();
}

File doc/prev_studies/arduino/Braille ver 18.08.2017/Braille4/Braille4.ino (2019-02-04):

//We always have to include the library
#include "LedControlMS.h"
#include <Wire.h>
#include <Adafruit_PWMServoDriver.h>
#include <SoftwareSerial.h>
#include <DFPlayer_Mini_Mp3.h>
Adafruit_PWMServoDriver pwm = Adafruit_PWMServoDriver();
#include <Keypad.h>
/*
  Now we need a LedControl to work with.
 ***** These pin numbers will probably not work with your hardware *****
  pin 12 is connected to the DataIn
  pin 11 is connected to the CLK
  pin 10 is connected to LOAD
  We have only a single MAX72XX.
*/
const byte ROWS = 4; //four rows
const byte COLS = 2; //four columns
//define the cymbols on the buttons of the keypads
char hexaKeys[ROWS][COLS] = {
  {1,4},
  {2,5},
  {3,6},
  {7,8}
};
byte rowPins[ROWS] = {5,4,3,2}; //connect to the row pinouts of the keypad
byte colPins[COLS] = {7,6}; //connect to the column pinouts of the keypad

//initialize an instance of class NewKeypad
Keypad customKeypad = Keypad( makeKeymap(hexaKeys), rowPins, colPins, ROWS, COLS); 

LedControl lc = LedControl(12, 10, 11, 1);

int mode;
bool flag1;
bool flag2;

#define enter 8

const byte IMG_OK[8] = {
  B01111110,
  B10000001,
  B10000001,
  B10000001,
  B10000001,
  B10000001,
  B10000001,
  B01111110
};

const byte IMG_NO[8] = {
  B10000001,
  B01000010,
  B00100100,
  B00011000,
  B00011000,
  B00100100,
  B01000010,
  B10000001
};
const byte A[8] = {
  B00011000,
  B00100100,
  B01000010,
  B01000010,
  B01111110,
  B01000010,
  B01000010,
  B01000010
};
const byte B[8] =
{
  B01111100,
  B01000000,
  B01000000,
  B01111100,
  B01000010,
  B01000010,
  B01000010,
  B01111100,
};
const byte V[8] =
{
  B01111000,
  B01000100,
  B01000100,
  B01111100,
  B01000010,
  B01000010,
  B01000010,
  B01111100,
};
const byte G[8] =
{
  B01111110,
  B01000010,
  B01000000,
  B01000000,
  B01000000,
  B01000000,
  B01000000,
  B01000000,
};
const byte D[8] =
{
  B00011000,
  B00100100,
  B00100100,
  B00100100,
  B00100100,
  B00100100,
  B01111110,
  B01000010,
};
const byte E[8] =
{
  B01111110,
  B01000000,
  B01000000,
  B01111100,
  B01111100,
  B01000000,
  B01000000,
  B01111110,
};
const byte YO[8] =
{
  B00101000,
  B01111100,
  B01000000,
  B01000000,
  B01111100,
  B01000000,
  B01000000,
  B01111100,
};

const  byte J[8] =
{
  B10000001,
  B10011001,
  B10011001,
  B11111111,
  B11111111,
  B10011001,
  B10011001,
  B10000001,
};

const byte Z[8] =
{
  B00111100,
  B00000010,
  B00000010,
  B00011100,
  B00000010,
  B00000010,
  B00000010,
  B00111100,
};

const byte I[8] =
{
  B01000010,
  B01000010,
  B01000110,
  B01001010,
  B01010010,
  B01100010,
  B01000010,
  B01000010,
};

const byte IY[8] =
{
  B00011000,
  B00000000,
  B01000010,
  B01000110,
  B01001010,
  B01010010,
  B01100010,
  B01000010,
};

const byte K [8] =
{
  B01000100,
  B01001000,
  B01010000,
  B01100000,
  B01010000,
  B01001000,
  B01000100,
  B01000010,
};

const byte L[8] =
{
  B00011000,
  B00100100,
  B01000010,
  B01000010,
  B01000010,
  B01000010,
  B01000010,
  B01000010,
};
const byte M[8] =
{
  B00000000,
  B10000010,
  B11000110,
  B10101010,
  B10010010,
  B10000010,
  B10000010,
  B10000010,
};

const byte N[8] =
{
  B00000000,
  B01000010,
  B01000010,
  B01000010,
  B01111110,
  B01000010,
  B01000010,
  B01000010,
};

const byte O[8] =
{
  B00111000,
  B01000100,
  B01000100,
  B01000100,
  B01000100,
  B01000100,
  B01000100,
  B00111000,
};
const byte P[8] =
{
  B01111110,
  B01000010,
  B01000010,
  B01000010,
  B01000010,
  B01000010,
  B01000010,
  B01000010,
};
const byte R[8] =
{
  B01111000,
  B01000100,
  B01000100,
  B01111000,
  B01000000,
  B01000000,
  B01000000,
  B01000000,
};
const byte S[8] =
{
  B00111100,
  B00100000,
  B00100000,
  B00100000,
  B00100000,
  B00100000,
  B00100000,
  B00111100
};
const byte T[8] =
{
  B11111111,
  B00011000,
  B00011000,
  B00011000,
  B00011000,
  B00011000,
  B00011000,
  B00011000,
};
const byte U[8] =
{
  B00100010,
  B00100010,
  B00100010,
  B00011110,
  B00000010,
  B00000010,
  B00000010,
  B00111100,
};
const byte F[8] =
{
  B11111110,
  B10010010,
  B10010010,
  B11111110,
  B00010000,
  B00010000,
  B00010000,
  B00010000,
};
const byte X[8] =
{
  B00000000,
  B10000010,
  B01000100,
  B00101000,
  B00010000,
  B00101000,
  B01000100,
  B10000010,
};
const byte CE[8] =
{
  B10000010,
  B10000010,
  B10000010,
  B10000010,
  B10000010,
  B10000010,
  B11111110,
  B00000011,
};
const byte C[8] =
{
  B01000100,
  B01000100,
  B01000100,
  B01000100,
  B00111100,
  B00000100,
  B00000100,
  B00000100,
};
const byte SH[8] =
{
  B10000010,
  B10010010,
  B10010010,
  B10010010,
  B10010010,
  B10010010,
  B11111110,
  B00000000,
};
const byte SHA[8] =
{
  B10000010,
  B10010010,
  B10010010,
  B10010010,
  B10010010,
  B10010010,
  B11111111,
  B00000001,
};
const byte HARD[8] =
{
  B00000000,
  B01100000,
  B00100000,
  B00100000,
  B00111100,
  B00100010,
  B00100010,
  B00111100,
};
const byte YI[8] =
{
  B10000001,
  B10000001,
  B10000001,
  B10000001,
  B11111001,
  B10000101,
  B10000101,
  B11111001,
};
const byte SOFT[8] =
{
  B01000000,
  B01000000,
  B01000000,
  B01000000,
  B01111000,
  B01000100,
  B01000100,
  B01111000,
};
const byte EE[8] =
{
  B01111000,
  B00000100,
  B00000010,
  B00111110,
  B00111110,
  B00000010,
  B00000100,
  B01111000,
};
const byte YOU[8] =
{
  B10001110,
  B10010001,
  B10010001,
  B11110001,
  B11110001,
  B10010001,
  B10010001,
  B10001110,
};
const byte YA[8] =
{
  B00111100,
  B01000100,
  B01000100,
  B00111100,
  B00001100,
  B00010100,
  B00100100,
  B01000100,
};
const byte WAR[8] =
{
  B00011000,
  B00011000,
  B00011000,
  B00011000,
  B00011000,
  B00000000,
  B00011000,
  B00011000,
};
const byte QU[8] =
{
  B00011000,
  B00100100,
  B00000100,
  B00001000,
  B00010000,
  B00010000,
  B00000000,
  B00010000,
};
const byte DOT[8] =
{
  B00000000,
  B00000000,
  B00000000,
  B00000000,
  B00000000,
  B00011000,
  B00011000,
  B00000000,
};
const byte SPACE[8] =
{
  B00000000,
  B00000000,
  B00000000,
  B00000000,
  B00000000,
  B00000000,
  B01111110,
  B00000000,
};
const byte MINUS[8] =
{
  B00000000,
  B00000000,
  B00000000,
  B11111111,
  B11111111,
  B00000000,
  B00000000,
  B00000000,
};
const byte PLUS[8] =
{
  B00011000,
  B00011000,
  B00011000,
  B11111111,
  B11111111,
  B00011000,
  B00011000,
  B00011000,
};
const byte ZAP[8] =
{
  B00000000,
  B00000000,
  B00000000,
  B00000000,
  B00011000,
  B00011000,
  B00001000,
  B00010000,
};
const byte TWODOTS[8] =
{
  B00000000,
  B00011000,
  B00011000,
  B00000000,
  B00000000,
  B00011000,
  B00011000,
  B00000000,
};
const byte DOTZAP[8] =
{
  B00000000,
  B00011000,
  B00011000,
  B00000000,
  B00011000,
  B00011000,
  B00001000,
  B00010000,
};
const byte NUM_ZERO[8] =
{ B00111100,
  B01000010,
  B01000010,
  B01000010,
  B01000010,
  B01000010,
  B01000010,
  B00111100
};
const byte NUM_ONE[8] =
{ B00001000,
  B00011000,
  B00101000,
  B00001000,
  B00001000,
  B00001000,
  B00001000,
  B00111100
};
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

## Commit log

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2019-01-28 parts to 3dprint and assembly added (SW 2014)
    [assembly.SLDASM, base.SLDPRT, bearing.SLDPRT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]
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2019-01-29 add estimate for 2019 winter school
    [fab_estimate.xlsx]
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2019-01-30 change setInside (some bugs still present)
    [calibrating.ino]
2019-01-30 finally fixed arduino test+calibrate
    [calibrating.ino]
2019-01-30 parts rearranged
    [assembly.SLDASM, base.SLDPRT, bearing.SLDPRT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]
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2019-01-31 add new part; modified gitignore not to track sld-15 aux files
    [pwm_shield.SLDPRT]
2019-01-31 Updated servo model properties.
    [servo.SLDPRT]
2019-01-31 update shield, create nano board (draft)
    [arduino_nano.SLDPRT, assembly.SLDASM, pwm_shield.SLDPRT]
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2019-02-01 add draft of printString function
    [servo.STL]
2019-02-02 add plywood to estimate
    [fab_estimate.xlsx]
2019-02-02 modelled details of Arduino Nano
    [arduino_nano.SLDPRT, assembly.SLDASM, pwm_shield.SLDPRT]
2019-02-02 decks added
    [assembly.SLDASM, deck_lower.SLDPRT, deck_upper.SLDPRT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]
2019-02-02 corner (draft)
    [assembly.SLDASM, corner.SLDPRT, deck_lower.SLDPRT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]
2019-02-02 Add joystick SW-model.
    [joystick.SLDPRT]
2019-02-02 modified trunk and other parts to fit the trunk
    [assembly.SLDASM, base.SLDPRT, corner.SLDPRT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]
2019-02-03 add leverSrort mirrored to parts to print (stl)
    [leverShort_r.STL]
2019-02-03 minor changes
    [assembly.SLDASM, deck_lower.SLDPRT, deck_upper.SLDPRT]
2019-02-03 Add speaker SW-model.
    [speaker.SLDPRT]
2019-02-03 add screws and modify corners
    [assembly.SLDASM, corner.SLDPRT, corner.STL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]
2019-02-03 Add side panels SW-model.
    [side-1.SLDPRT]
2019-02-03 Add long panel SW-model.
    [side-2.SLDPRT]
2019-02-04 modify sides, make dxf
    [assembly.SLDASM, side-1.DXF, side-1.SLDPRT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]
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2019-02-04 Change printString to remain in correct positions after job
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2019-02-04 widen shaft (still narrow), add logic to educational app
    [assembly.SLDASM, base.SLDPRT, bearing_shaft.STL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]
2019-02-04 Add joystick-base SW-model (ver. 1)
    [joystick-base.SLDPRT]
2019-02-05 add/modify supports for joystick and shield
    [asm_shield.SLDASM, assembly.SLDASM, joystick-base.SLDPRT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]
2019-02-05 Add correct async in printText
    [printText.ino]
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2019-02-05 improve supports
    [assembly.SLDASM, joystick-base.SLDPRT, joystick-base.STL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]
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2019-02-06 add speaker support and drumstick
    [assembly.SLDASM, drumstick.SLDPRT, drumstick.STL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]
2019-02-06 Complete issue31, all commands work. You need to put right lessons into python/lesson
    [joystick.py, main.py]
2019-02-07 Add button placement sketch.
    [deck_upper.SLDPRT]
2019-02-07 add wire cover to parts
    [wire_cover.SLDPRT, wire_cover.STL]
2019-02-07 improve assembly
    [assembly.SLDASM, drumstick.SLDPRT, m4nut.SLDPRT]
2019-02-07 Add delay between letters. Find a new bug (issue 35)
    [main.py]
2019-02-07 Add mute button, pin and 'chocolate tile' SW-models.
    [button.SLDPRT, chocolate.SLDPRT, pin.SLDPRT]
2019-02-07 Complete bug from issue31
    [joystick.py, main.py, printText.ino]
2019-02-07 rendered finally, presentation added
    [assembly.SLDASM, button.SLDPRT, chocolate.SLDPRT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]
2019-02-07 fix some bugs with audio and tests
    [joystick.py, main.py, printText.ino]
2019-02-07 Fix printing letters on screen
    [main.py]
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2019-02-08 Add keyboard button SW-model.
    [keyboard button.SLDPRT]
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2019-02-10 parts rearrange, add to git Large File System
    [Emblem.SLDPRT, Emblem.STL, arduino_nano.SLDPRT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]
2019-02-10 move neural net into python/neural_net, add wav to git LFS
    [wire_cover.SLDPRT]
2019-02-16 add hotfix for button cover
    [chocolate_hotfix.SLDPRT, chocolate_hotfix.STL]
2019-03-01 braille2: working cell; python:minor fixes
    [asm.SLDASM, asmx6.SLDASM, asmx6_part_base.SLDASM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]
2019-03-03 decrease rack width by 0.05 mm
    [asmx6.SLDASM, gear_asm.SLDPRT, gear_asm.STL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]
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2019-03-07 tweak pwm shield dimensions
    [PWM Shield.SLDPRT]
2019-03-07 create assembly with linear motors servo
    [ASM.SLDASM, PWM Shield.SLDPRT, arduino_nano.SLDPRT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]
2019-03-08 tweak cell for better fitting
    [asmx6.SLDASM, cell_housing.SLDPRT, housing.SLDPRT]
2019-03-08 Add correct sending char from keyboard to serial.
    [printText.ino]
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2019-03-16 Update joystick.SLDPRT
    New version of joystick.
    [joystick.SLDPRT]
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2019-03-19 tweak back_lid dimensions, add dxf2
    [ASM.SLDASM, asmx6.SLDASM, back_lid.SLDPRT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]
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2019-03-22 modify keypad, ArdNano, ard support, roll back cellHousing
    [ASM.SLDASM, arduino_nano.SLDPRT, asmx6.SLDASM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]
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2019-03-22 add upperDeck dxf, fix error in asmx6partBase
    [asmx6_part_base.SLDASM, asmx6_part_base.SLDPRT, asmx6_part_base.STL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]
2019-03-23 add opening in back side
    [ASM.SLDASM, side-long-back.DXF, side-long-back.SLDPRT]
2019-03-24 Minor bug fixes. Needs more improvements
    [notes.py]
2019-03-24 fix not connecting to comp by rolling back LOOP
    [printText.ino]
2019-03-24 fix not connecting to comp by rolling back LOOP (PWM)
    [printTextPWM.ino]
2019-03-25 add USB cover (small)+nest (v1)
    [ASM.SLDASM, usbCoverSmall.SLDPRT, usbNest.SLDPRT]
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2019-03-26 new chocolate; tweak jack
    [ASM.SLDASM, chocolate2.SLDPRT, jack.SLDPRT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]
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2019-03-30 Issue 70 (buttons sounds and "c" for joystick button)
    [printTextPWM.ino]
2019-03-31 comment (suppress) unstable asynchronic printLine
    [serial_hex.py]
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2019-03-31 stable ps voice_recognition, performance improved
    [feat.params]
2019-04-04 arduino:keyboard mapping change! other:minor changes
    [ASM.SLDASM, corner_joystick.SLDPRT, corner_joystick.STL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]
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2019-04-06 change gear diameter for new servos
    [ASM.SLDASM, asmx6.SLDASM, gear.SLDPRT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]
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2019-04-08 improved and commented speech recognition. Still fails sometimes
    [edu_app.py, listen.py, main.py]
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2019-04-13 add space key, help button (thx Ivan Begun)
    [ASM.SLDASM, asmx6.SLDASM, corner_joystick.SLDPRT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]
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2019-04-14 add space key support (Ivan Begun's work)
    [ASM.SLDASM, arch.SLDPRT, hold.SLDPRT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]
2019-04-17 modify upper deck, tweak spaceButton support
    [ASM.SLDASM, arch.SLDPRT, asmx6.SLDASM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]
2019-04-19 fix exception with text var in notes. calibrate old machine
    [calibrating.ino, main.py, printText.ino]
2019-04-19 add inscription on side_long
    [side-long.DXF, side-long.SLDPRT]
2019-04-19 tweak back_lid, gears, deck_upper for cell2_1
    [ASM.SLDASM, asmx6.SLDASM, back_lid.SLDPRT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]
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2019-04-28 modify keyboard for v2_1; usbNest - better fitting
    [chocolate2TrV2_1.SLDPRT, space.SLDPRT, space.STL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]
2019-04-30 fix false printLine breaks
    [listen_serial.py]
2019-04-30 add screws to ASM
    [ASM.SLDASM, m4nut.SLDPRT, m4x20screw.SLDPRT]
2019-05-02 main.py - modify error handling to listen full message
    [main.py]
2019-05-03 upd main, blitz(still buging)
    [blitz.py, main.py]
2019-05-03 Add help to alphabet app and lessons. Minor bug fixes
    [alphabet.py, edu_app.py, help.py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]
2019-05-07 Create expl.SLDASM
    Позже надо покрасить детали для большей контрастности и отфотографировать. Работа в процессе
    [expl.SLDASM]
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
